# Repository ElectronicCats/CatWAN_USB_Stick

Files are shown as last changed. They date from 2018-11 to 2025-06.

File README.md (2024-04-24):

# CatWAN USB Stick
<p align="center">
    <a href="https://github.com/ElectronicCats/CatWAN_USB_Stick/wiki">
        CatWANShield
    </a>
</p>

<p align=center>
    <a href="https://electroniccats.com/store/catwan-usb-stick">
        
    </a>
    <a href="https://github.com/ElectronicCats/CatWAN_USB_Stick/wiki">
        
    </a>
</p>

<p align=center>
Also available at distributors:
</p>
<p align=center>
<a href="https://labs.ksec.co.uk/product-category/electronic-cat/">

</a>
</p>

Are you interested in learning how LoRa works at the package level? Debugging your own LoRa hardware and trying to detect where something is wrong? Or maybe you're writing a custom application for your Internet of Things (IoT) network with LoraWAN? We have the perfect tool for you!

This CatWAN USB Stick is programmed with a special firmware image that makes it an easy-to-use LoRa sniffer. You can passively capture the data exchanges between two LoRa devices, capturing with our "LoRa Sniffer" the open-source network analysis tool that we have created to use together.

This device can work in networks LoRaWAN compatible with classes A, B, and C, although currently we do not have a firmware for this way of working, the CatWAN firmware is completely open source and you can find it in our repository along with the schematic. If you want to reprogram this device you can do it through Arduino IDE and its USB port or if you do not have to use a J-Link. ATMEL-ICE or a DIY SWD programmer

This device has a SAMD21 ARM Cortex microcontroller at 48Mhz with native USB 2.1, with 256Kb for programming, compatible with Arduino and Circuit Python.

Check our repository for more details and software downloads!

### Main characteristics

- Works with any PC, Raspberry Pi or BeagleBone, even a smartphone or tablet
- Supports packet mode LoRa® (package mode) or LoRaWAN ™ Class A, B and C
- Compatible with The Things Network and other LoRaWAN networks
- Based on the RFM95
- RX LED as reception indicator, programmable by the user
- Easy reprogramming compatible with Arduino and Circuit Python
- Compatible with the [App LoRa Sniffer](https://github.com/ElectronicCats/LoRa_Sniffer)
- Open Source

### Specifications

- Connectivity: USB 2.1
- Power Consumption: 140 ma typical TX, 20 ma idle (with power LED)
- Receiver Sensitivity: down to -146 dBm
- TX Power: adjustable up to +18.5 dBm
- Range: up to 15 km coverage in suburban and up to 5 km coverage in urban areas

### Pin connections

|Arduino | Port | RFM Function|
|---|---|---|
|0 | PORTA4  | DIO0 |
|1 | PORTA23 | DIO1 |
|2 | PORTA27 | DIO2 |
|13 | PORTA14 | LED |
|15 | PORTA15 | DIO5 |
|17 | PORTA22 | MISO |
|18 | PORTA18 | MOSI |
|19 | PORTA19 | SCK |
|20 | PORTA17 | SS |

## How to contribute 
 Contributions are welcome! 

Please read the document  [**Contribution Manual**](https://github.com/ElectronicCats/electroniccats-cla/blob/main/electroniccats-contribution-manual.md)  which will show you how to contribute your changes to the project.

✨ Thanks to all our [contributors](https://github.com/ElectronicCats/CatWAN_USB_Stick/graphs/contributors)! ✨

See  [**_Electronic Cats CLA_**](https://github.com/ElectronicCats/electroniccats-cla/blob/main/electroniccats-cla.md) for more information.

See the [**community code of conduct**](https://github.com/ElectronicCats/electroniccats-cla/blob/main/electroniccats-community-code-of-conduct.md)   for a vision of the community we want to build and what we expect from it.

### Maintainer

Electronic Cats invests time and resources in providing this open-source design design, please support Electronic Cats and open-source hardware by purchasing products from Electronic Cats!

<a href="https://github.com/sponsors/ElectronicCats">
  
</a>

## Open Source certified.
<p align="center">
    <a href="https://www.oshwa.org/cert">
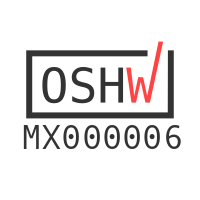
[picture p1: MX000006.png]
CatWANShield
        
        <br>
        <strong>[OSHW] MX000006 | Certified open source hardware |</strong>
    </a>
</p>

Designed by Electronic Cats.

Firmware released under an GNU AGPL v3.0 license. See the LICENSE file for more information.

Hardware released under an CERN Open Hardware Licence v1.2. See the LICENSE_HARDWARE file for more information.

Electronic Cats is a registered trademark, please do not use if you sell these PCBs.

27 May 2019

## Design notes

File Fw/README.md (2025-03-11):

# Firmware examples
This folder contains 3 sub-folders:

- LoRaWAN
- LoRa-PHY
- bootloader_uf2 for only SAMD21 version

The sub-folder bootloader_uf2 has inside all the files that can be use to re-flash your CatWAN USB-Stick in case of hard brick it.

The sub-folders LoRa and LoRaWAN have inside its own examples about a posible implementation of LoRa from LoRa physical layer to some LoRaWAN implementations. 

## LoRaWAN Folder
Here you will find three possible ways to implement a LoRaWAN Stack:

- LoRa_WAN_Sniffer_REG
	Which is an example where you only require the SPI library and all the registers inside the radio are modified just as the LoRaWAN stack says.

- LMIC_library 
	In this folder you'll find two examples about an implementation of the LoRaWAN Stack with the LMIC library with the two types of activations, ABP and OTAA, both examples are a class A node, for this examples you MUST install the [LMIC library](https://github.com/things-nyc/arduino-lmic).
	
- ArduinoLoRaWAN_library 
	In this folder you'll find an example of the LoRaWAN stack implementation with the ArduinoLoRaWAN library which is simple than the LMIC implementation, for this examples you MUST install the [Arduino LoRaWAN library](https://github.com/BeelanMX/arduino-LoRaWAN)
	
## LoRa_PHY 
Here you'
ll find the simplest examples to use the LoRa radio just using the physical layer of LoRa 

- "LoRaReceiverCallback" 
   Will receive any LoRa data from an interrupt
- "LoRaSender" 
	Will send data on the physical layer of LoRa
- "LoRa_PHY_Sniffer"
	Will receive any packet an is under development to configure the radio over serial communication
- "Relay Stick"
	Will communicate with the CatWAN Relay board to control and monitor relays.
- "LoRaReceiver"
    Will receive any LoRa data without an interrupt
- "LoRaSniffer"

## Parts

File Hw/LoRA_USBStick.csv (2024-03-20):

# | Reference | Qty | Value | Footprint | DNP | LCSC# | manf#
1 | AE1 | 1 | Antenna_Shield | agroin:SMA_EDGE |  | C2913580
2 | C1, C3 | 2 | 27pF | Capacitor_SMD:C_0603_1608Metric |  |  | C0603C270J5GAC7411
3 | C2, C9 | 2 | 1uF | Capacitor_SMD:C_0603_1608Metric |  | C711096
4 | C4, C8, C10, C11, C12, C13, C14, C15, C16, C17 | 10 | 0.1uF | Capacitor_SMD:C_0603_1608Metric |  | C282519
5 | C5 | 1 | 0.1uF | Capacitor_SMD:C_0805_2012Metric_Pad1.15x1.40mm_HandSolder |  |  | 885012207072
6 | C6, C7 | 2 | 10uF | Capacitor_SMD:C_0805_2012Metric_Pad1.15x1.40mm_HandSolder |  | C1713
7 | D1 | 1 | Rx | LED_SMD:LED_0805_2012Metric_Pad1.15x1.40mm_HandSolder |  |  | APT2012SGC
8 | D2 | 1 | ON | LED_SMD:LED_0805_2012Metric_Pad1.15x1.40mm_HandSolder |  |  | AP2012EC
9 | J10 | 1 | USB_B | Connectors:C46394 |  | C46394
10 | JP1 | 1 | BOOT | Jumper:SolderJumper-2_P1.3mm_Open_Pad1.0x1.5mm | DNP
11 | R2 | 1 | 1K | Resistor_SMD:R_0603_1608Metric |  | C21190
12 | R3, R4 | 2 | 27 | Resistor_SMD:R_0603_1608Metric |  | C2907136
13 | R5 | 1 | 10K | Resistor_SMD:R_0603_1608Metric |  | C2930027
14 | R9, R11 | 2 | 120R | Resistor_SMD:R_0603_1608Metric |  |  | RMC1/10K1200FTP
15 | SW3 | 1 | RST | Switches:C455281 |  |  | B3U-1000P
16 | U1 | 1 | RP2040 | RP2040:RP2040-QFN-56 |  | C2040
17 | U2 | 1 | RFM95W-868S2 | RF_Module:HOPERF_RFM9XW_SMD |  |  | 109990166
18 | U3 | 1 | AP2112K-3.3 | Package_TO_SOT_SMD:SOT-23-5 |  |  | AP7365-33WG-7
19 | U4 | 1 | W25Q16JV | RP2040:W25Q16JVUUIQ |  |  | W25Q16JVUUIQTR
20 | Y1 | 1 | 12Mhz | Crystal:Crystal_SMD_5032-2Pin_5.0x3.2mm |  |  | ECS-120-18-30-JGN-TR

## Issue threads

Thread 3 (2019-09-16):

Can't program LoRa sniffer firmware to V1.0 board

Miceuz, 2019-09-16:
This is the build log I get:

This is build log I get when programming LoRa sniffer:

/home/miceuz/arduino/arduino-builder -dump-prefs -logger=machine -hardware /home/miceuz/arduino/hardware -hardware /home/miceuz/.arduino15/packages -tools /home/miceuz/arduino/tools-builder -tools /home/miceuz/arduino/hardware/tools/avr -tools /home/miceuz/.arduino15/packages -built-in-libraries /home/miceuz/arduino/libraries -libraries /home/miceuz/Arduino/libraries -fqbn=electroniccats:samd:electroniccats_USB_Stick -vid-pid=0X1209_0XBAB2 -ide-version=10807 -build-path /tmp/arduino_build_279491 -warnings=none -build-cache /tmp/arduino_cache_751360 -prefs=build.warn_data_percentage=75 -prefs=runtime.tools.CMSIS-Atmel.path=/home/miceuz/.arduino15/packages/arduino/tools/CMSIS-Atmel/1.2.0 -prefs=runtime.tools.CMSIS-Atmel-1.2.0.path=/home/miceuz/.arduino15/packages/arduino/tools/CMSIS-Atmel/1.2.0 -prefs=runtime.tools.arm-none-eabi-gcc.path=/home/miceuz/.arduino15/packages/arduino/tools/arm-none-eabi-gcc/4.8.3-2014q1 -prefs=runtime.tools.arm-none-eabi-gcc-4.8.3-2014q1.path=/home/miceuz/.arduino15/packages/arduino/tools/arm-none-eabi-gcc/4.8.3-2014q1 -prefs=runtime.tools.bossac.path=/home/miceuz/.arduino15/packages/arduino/tools/bossac/1.8.0-48-gb176eee -prefs=runtime.tools.bossac-1.8.0-48-gb176eee.path=/home/miceuz/.arduino15/packages/arduino/tools/bossac/1.8.0-48-gb176eee -prefs=runtime.tools.openocd.path=/home/miceuz/.arduino15/packages/arduino/tools/openocd/0.9.0-arduino -prefs=runtime.tools.openocd-0.9.0-arduino.path=/home/miceuz/.arduino15/packages/arduino/tools/openocd/0.9.0-arduino -prefs=runtime.tools.CMSIS.path=/home/miceuz/.arduino15/packages/arduino/tools/CMSIS/4.5.0 -prefs=runtime.tools.CMSIS-4.5.0.path=/home/miceuz/.arduino15/packages/arduino/tools/CMSIS/4.5.0 -verbose /home/miceuz/Arduino/LoRaSniffer/LoRaSniffer.ino
/home/miceuz/arduino/arduino-builder -compile -logger=machine -hardware /home/miceuz/arduino/hardware -hardware /home/miceuz/.arduino15/packages -tools /home/miceuz/arduino/tools-builder -tools /home/miceuz/arduino/hardware/tools/avr -tools /home/miceuz/.arduino15/packages -built-in-libraries /home/miceuz/arduino/libraries -libraries /home/miceuz/Arduino/libraries -fqbn=electroniccats:samd:electroniccats_USB_Stick -vid-pid=0X1209_0XBAB2 -ide-version=10807 -build-path /tmp/arduino_build_279491 -warnings=none -build-cache /tmp/arduino_cache_751360 -prefs=build.warn_data_percentage=75 -prefs=runtime.tools.CMSIS-Atmel.path=/home/miceuz/.arduino15/packages/arduino/tools/CMSIS-Atmel/1.2.0 -prefs=runtime.tools.CMSIS-Atmel-1.2.0.path=/home/miceuz/.arduino15/packages/arduino/tools/CMSIS-Atmel/1.2.0 -prefs=runtime.tools.arm-none-eabi-gcc.path=/home/miceuz/.arduino15/packages/arduino/tools/arm-none-eabi-gcc/4.8.3-2014q1 -prefs=runtime.tools.arm-none-eabi-gcc-4.8.3-2014q1.path=/home/miceuz/.arduino15/packages/arduino/tools/arm-none-eabi-gcc/4.8.3-2014q1 -prefs=runtime.tools.bossac.path=/home/miceuz/.arduino15/packages/arduino/tools/bossac/1.8.0-48-gb176eee -prefs=runtime.tools.bossac-1.8.0-48-gb176eee.path=/home/miceuz/.arduino15/packages/arduino/tools/bossac/1.8.0-48-gb176eee -prefs=runtime.tools.openocd.path=/home/miceuz/.arduino15/packages/arduino/tools/openocd/0.9.0-arduino -prefs=runtime.tools.openocd-0.9.0-arduino.path=/home/miceuz/.arduino15/packages/arduino/tools/openocd/0.9.0-arduino -prefs=runtime.tools.CMSIS.path=/home/miceuz/.arduino15/packages/arduino/tools/CMSIS/4.5.0 -prefs=runtime.tools.CMSIS-4.5.0.path=/home/miceuz/.arduino15/packages/arduino/tools/CMSIS/4.5.0 -verbose /home/miceuz/Arduino/LoRaSniffer/LoRaSniffer.ino
Using board 'electroniccats_USB_Stick' from platform in folder: /home/miceuz/.arduino15/packages/electroniccats/hardware/samd/1.1.1
Using core 'arduino' from platform in folder: /home/miceuz/.arduino15/packages/electroniccats/hardware/samd/1.1.1
Build options changed, rebuilding all
Detecting libraries used...
/home/miceuz/.arduino15/packages/arduino/tools/arm-none-eabi-gcc/4.8.3-2014q1/bin/arm-none-eabi-g++ -mcpu=cortex-m0plus -mthumb -c -g -Os -w -std=gnu++11 -ffunction-sections -fdata-sections -fno-threadsafe-statics -nostdlib --param max-inline-insns-single=500 -fno-rtti -fno-exceptions -w -x c++ -E -CC -DF_CPU=48000000L -DARDUINO=10807 -DARDUINO_catwan_usb_stick -DARDUINO_ARCH_SAMD -DCRYSTALLESS -DARDUINO_SAMD_ZERO -D__SAMD21E18A__ -DARM_MATH_CM0PLUS -DUSB_VID=0x1209 -DUSB_PID=0xBAB2 -DUSBCON "-DUSB_MANUFACTURER=\"Electronic Cats\"" "-DUSB_PRODUCT=\"CatWAN USB_Stick\"" -I/home/miceuz/.arduino15/packages/arduino/tools/CMSIS/4.5.0/CMSIS/Include/ -I/home/miceuz/.arduino15/packages/arduino/tools/CMSIS-Atmel/1.2.0/CMSIS/Device/ATMEL/ -I/home/miceuz/.arduino15/packages/electroniccats/hardware/samd/1.1.1/cores/arduino -I/home/miceuz/.arduino15/packages/electroniccats/hardware/samd/1.1.1/variants/catwan_usb_stick /tmp/arduino_build_279491/sketch/LoRaSniffer.ino.cpp -o /dev/null
/home/miceuz/.arduino15/packages/arduino/tools/arm-none-eabi-gcc/4.8.3-2014q1/bin/arm-none-eabi-g++ -mcpu=cortex-m0plus -mthumb -c -g -Os -w -std=gnu++11 -ffunction-sections -fdata-sections -fno-threadsafe-statics -nostdlib --param max-inline-insns-single=500 -fno-rtti -fno-exceptions -w -x c++ -E -CC -DF_CPU=48000000L -DARDUINO=10807 -DARDUINO_catwan_usb_stick -DARDUINO_ARCH_SAMD -DCRYSTALLESS -DARDUINO_SAMD_ZERO -D__SAMD21E18A__ -DARM_MATH_CM0PLUS -DUSB_VID=0x1209 -DUSB_PID=0xBAB2 -DUSBCON "-DUSB_MANUFACTURER=\"Electronic Cats\"" "-DUSB_PRODUCT=\"CatWAN USB_Stick\"" -I/home/miceuz/.arduino15/packages/arduino/tools/CMSIS/4.5.0/CMSIS/Include/ -I/home/miceuz/.arduino15/packages/arduino/tools/CMSIS-Atmel/1.2.0/CMSIS/Device/ATMEL/ -I/home/miceuz/.arduino15/packages/electroniccats/hardware/samd/1.1.1/cores/arduino -I/home/miceuz/.arduino15/packages/electroniccats/hardware/samd/1.1.1/variants/catwan_usb_stick -I/home/miceuz/Arduino/libraries/ArduinoSerialCommand /tmp/arduino_build_279491/sketch/LoRaSniffer.ino.cpp -o /dev/null
/home/miceuz/.arduino15/packages/arduino/tools/arm-none-eabi-gcc/4.8.3-2014q1/bin/arm-none-eabi-g++ -mcpu=cortex-m0plus -mthumb -c -g -Os -w -std=gnu++11 -ffunction-sections -fdata-sections -fno-threadsafe-statics -nostdlib --param max-inline-insns-single=500 -fno-rtti -fno-exceptions -w -x c++ -E -CC -DF_CPU=48000000L -DARDUINO=10807 -DARDUINO_catwan_usb_stick -DARDUINO_ARCH_SAMD -DCRYSTALLESS -DARDUINO_SAMD_ZERO -D__SAMD21E18A__ -DARM_MATH_CM0PLUS -DUSB_VID=0x1209 -DUSB_PID=0xBAB2 -DUSBCON "-DUSB_MANUFACTURER=\"Electronic Cats\"" "-DUSB_PRODUCT=\"CatWAN USB_Stick\"" -I/home/miceuz/.arduino15/packages/arduino/tools/CMSIS/4.5.0/CMSIS/Include/ -I/home/miceuz/.arduino15/packages/arduino/tools/CMSIS-Atmel/1.2.0/CMSIS/Device/ATMEL/ -I/home/miceuz/.arduino15/packages/electroniccats/hardware/samd/1.1.1/cores/arduino -I/home/miceuz/.arduino15/packages/electroniccats/hardware/samd/1.1.1/variants/catwan_usb_stick -I/home/miceuz/Arduino/libraries/ArduinoSerialCommand -I/home/miceuz/.arduino15/packages/electroniccats/hardware/samd/1.1.1/libraries/SPI /tmp/arduino_build_279491/sketch/LoRaSniffer.ino.cpp -o /dev/null
/home/miceuz/.arduino15/packages/arduino/tools/arm-none-eabi-gcc/4.8.3-2014q1/bin/arm-none-eabi-g++ -mcpu=cortex-m0plus -mthumb -c -g -Os -w -std=gnu++11 -ffunction-sections -fdata-sections -fno-threadsafe-statics -nostdlib --param max-inline-insns-single=500 -fno-rtti -fno-exceptions -w -x c++ -E -CC -DF_CPU=48000000L -DARDUINO=10807 -DARDUINO_catwan_usb_stick -DARDUINO_ARCH_SAMD -DCRYSTALLESS -DARDUINO_SAMD_ZERO -D__SAMD21E18A__ -DARM_MATH_CM0PLUS -DUSB_VID=0x1209 -DUSB_PID=0xBAB2 -DUSBCON "-DUSB_MANUFACTURER=\"Electronic Cats\"" "-DUSB_PRODUCT=\"CatWAN USB_Stick\"" -I/home/miceuz/.arduino15/packages/arduino/tools/CMSIS/4.5.0/CMSIS/Include/ -I/home/miceuz/.arduino15/packages/arduino/tools/CMSIS-Atmel/1.2.0/CMSIS/Device/ATMEL/ -I/home/miceuz/.arduino15/packages/electroniccats/hardware/samd/1.1.1/cores/arduino -I/home/miceuz/.arduino15/packages/electroniccats/hardware/samd/1.1.1/variants/catwan_usb_stick -I/home/miceuz/Arduino/libraries/ArduinoSerialCommand -I/home/miceuz/.arduino15/packages/electroniccats/hardware/samd/1.1.1/libraries/SPI -I/home/miceuz/Arduino/libraries/LoRa/src /tmp/arduino_build_279491/sketch/LoRaSniffer.ino.cpp -o /dev/null
/home/miceuz/.arduino15/packages/arduino/tools/arm-none-eabi-gcc/4.8.3-2014q1/bin/arm-none-eabi-g++ -mcpu=cortex-m0plus -mthumb -c -g -Os -w -std=gnu++11 -ffunction-sections -fdata-sections -fno-threadsafe-statics -nostdlib --param max-inline-insns-single=500 -fno-rtti -fno-exceptions -w -x c++ -E -CC -DF_CPU=48000000L -DARDUINO=10807 -DARDUINO_catwan_usb_stick -DARDUINO_ARCH_SAMD -DCRYSTALLESS -DARDUINO_SAMD_ZERO -D__SAMD21E18A__ -DARM_MATH_CM0PLUS -DUSB_VID=0x1209 -DUSB_PID=0xBAB2 -DUSBCON "-DUSB_MANUFACTURER=\"Electronic Cats\"" "-DUSB_PRODUCT=\"CatWAN USB_Stick\"" -I/home/miceuz/.arduino15/packages/arduino/tools/CMSIS/4.5.0/CMSIS/Include/ -I/home/miceuz/.arduino15/packages/arduino/tools/CMSIS-Atmel/1.2.0/CMSIS/Device/ATMEL/ -I/home/miceuz/.arduino15/packages/electroniccats/hardware/samd/1.1.1/cores/arduino -I/home/miceuz/.arduino15/packages/electroniccats/hardware/samd/1.1.1/variants/catwan_usb_stick -I/home/miceuz/Arduino/libraries/ArduinoSerialCommand -I/home/miceuz/.arduino15/packages/electroniccats/hardware/samd/1.1.1/libraries/SPI -I/home/miceuz/Arduino/libraries/LoRa/src /home/miceuz/Arduino/libraries/ArduinoSerialCommand/SerialCommand.cpp -o /dev/null
/home/miceuz/.arduino15/packages/arduino/tools/arm-none-eabi-gcc/4.8.3-2014q1/bin/arm-none-eabi-g++ -mcpu=cortex-m0plus -mthumb -c -g -Os -w -std=gnu++11 -ffunction-sections -fdata-sections -fno-threadsafe-statics -nostdlib --param max-inline-insns-single=500 -fno-rtti -fno-exceptions -w -x c++ -E -CC -DF_CPU=48000000L -DARDUINO=10807 -DARDUINO_catwan_usb_stick -DARDUINO_ARCH_SAMD -DCRYSTALLESS -DARDUINO_SAMD_ZERO -D__SAMD21E18A__ -DARM_MATH_CM0PLUS -DUSB_VID=0x1209 -DUSB_PID=0xBAB2 -DUSBCON "-DUSB_MANUFACTURER=\"Electronic Cats\"" "-DUSB_PRODUCT=\"CatWAN USB_Stick\"" -I/home/miceuz/.arduino15/packages/arduino/tools/CMSIS/4.5.0/CMSIS/Include/ -I/home/miceuz/.arduino15/packages/arduino/tools/CMSIS-Atmel/1.2.0/CMSIS/Device/ATMEL/ -I/home/miceuz/.arduino15/packages/electroniccats/hardware/samd/1.1.1/cores/arduino -I/home/miceuz/.arduino15/packages/electroniccats/hardware/samd/1.1.1/variants/catwan_usb_stick -I/home/miceuz/Arduino/libraries/ArduinoSerialCommand -I/home/miceuz/.arduino15/packages/electroniccats/hardware/samd/1.1.1/libraries/SPI -I/home/miceuz/Arduino/libraries/LoRa/src /home/miceuz/.arduino15/packages/electroniccats/hardware/samd/1.1.1/libraries/SPI/SPI.cpp -o /dev/null
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
Miceuz, 2019-09-16:
Upon closer inspection I have noticed that two pads of RFM95 module were hanging above board, not soldered. Works after fixing this.

wero1414, 2019-09-17:
Great! I'm really ashamed that you needed to solder those RFM pins i really apologize, all the hardware that we provide is tested before shipping but i guess we miss one quality procedure.

If you want to buy any other thing from us we can give a discount to you cause this situation.

Closed 2019-09-17.

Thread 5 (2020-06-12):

Lack of build instructions

BatchDrake, 2020-06-12:
Hi all,

I'm trying to use the LoRa PHY Sniffer example, but I'm having trouble making it work. First of all, after installing the corresponding board description as you suggest in your README, I faced the following build issue:

```
LoRaSniffer:20:27: fatal error: SerialCommand.h: No such file or directory
 #include <SerialCommand.h>
```

My guess was that it depended on `SerialCommand`, but this library does not show up in the library manager. I looked it up on GitHub and, after finding multiple mutually-incompatible implementations of the same library, I came across this one (https://github.com/kroimon/Arduino-SerialCommand) which seemed to build. The problem now is that LoRaSniffer does not get past these lines:

```c++
void setup(){
  pinMode(LED_BUILTIN,OUTPUT);      // Configure the onboard LED for output
  digitalWrite(LED_BUILTIN,LOW);    // default to LED off
  pinMode(RFM_DIO5,INPUT);
  Serial.begin(115200);
  while (!Serial);
```

which don't seem to be related to `SerialCommand` at all. I know the bootloader works because if I set the `LED_BUILTIN` to `HIGH` right before initializing the serial, the green LED lights it up. However, if I set it right after the `while(!Serial)`, the LED remains switched off.

I think I may be missing a primary source of documentation here. The only thing I need is to read the contents of the LoRa PHY frames from Putty, that would be pretty much it. Is there a guide somewhere with detailed steps on how to build & use this sniffer?

Thanks!

sabas1080, 2020-06-12:
Hi @BatchDrake

`  while (!Serial);`

wait for serial port to open via Arduino IDE or Putty, after that you would see

```
  Serial.println("Welcome to the LoRa Sniffer CLI " + String(fwVersion,1) + "v\n");
  Serial.println("With this sketch you can scan the LoRa spectrum");
  Serial.println("Changing the Frequency, Spreading Factor, BandWidth or the IQ signals of the radio.");
  Serial.println("Type help to get the available commands.");
  Serial.println("Electronic Cats ® 2020");
```
if you don´t open serial port, the program will not advance

BatchDrake, 2020-06-12:
Waited for minutes with no results. Pressing Enter or typing `help` didn't
work either. Port speed was 115200.

El vie., 12 jun. 2020 19:34, Sabas <notifications@github.com> escribió:

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

sabas1080, 2020-06-12:
You have to active in serial monitor New Line and carriage Return and send command "help please"

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

BatchDrake, 2020-06-15:
Okay, it works now. Thanks!

Closed 2020-06-15.

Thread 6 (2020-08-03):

no 3.3V output and bootloader issue(not sure)

vileer, 2020-08-03:
I am trying to make my own board with the USB type-c connector but it didn't work, after review the hw design, I found the AP2112k-3.3 EN pin does not connect to the hight voltage which means no 3.3v output. After I connect the EN pin to VBUS, led lights up and able to program the bootloader. The official catwan stick I bought from tindie didn't have this issue.

But here comes the new problem, after flash the bootloader and plug it into the pc, nothing happens no USB-Serial port show in the Arduino IDE.

sabas1080, 2020-08-03:
Hi @vileer

it seems this change I don't update, we have repaired the LDO.

About the bootloader, are you pressing the reset button twice quickly and going into boot mode?

vileer, 2020-08-04:
@sabas1080 Yes, I did double click the reset button quickly, but nothing happens.

vileer, 2020-08-04:
Here is my fuses setting, may that help you to diagnos the problem：
SERIAL_NUMBER_3 = 0x41F61D1A
SERIAL_NUMBER_0 = 0x51514B32
SERIAL_NUMBER_1 = 0x53202020
SERIAL_NUMBER_2 = 0xFF07392C
ADC_LINEARITY_0 = 0x08
ADC_LINEARITY_1 = 0x04
ADC_BIASCAL = 0x03
OSC32K_CAL = 0x32
USB_TRANSN = 0x09
USB_TRANSP = 0x19
USB_TRIM = 0x06
DFLL48M_COARSE_CAL = 0x1E
DFLL48M_FINE_CAL = 0x200
ROOM_TEMP_VAL_INT = 0x1E
ROOM_TEMP_VAL_DEC = 0x01
HOT_TEMP_VAL_INT = 0x55
HOT_TEMP_VAL_DEC = 0x00
ROOM_INT1V_VAL = 0xF7
HOT_INT1V_VAL = 0xF4
ROOM_ADC_VAL = 0xAFA
HOT_ADC_VAL = 0xD1E
NVMCTRL_BOOTPROT = SIZE_0BYTES
NVMCTRL_EEPROM_SIZE = SIZE_0BYTES
BOD33USERLEVEL = 0x07
BOD33_EN = ENABLED
BOD33_ACTION = RESET
WDT_ENABLE = DISABLED
WDT_ALWAYSON = DISABLED
WDT_PER = CYC16384
WDT_WINDOW_0 = [X]
WDT_WINDOW_1 = 0x05
WDT_EWOFFSET = CYC16384
WDT_WEN = DISABLED
BOD33_HYST = DISABLED
NVMCTRL_REGION_LOCKS = 0xFFFF

AUX3_WORD_3 = 0x41F61D1A (valid)
AUX3_WORD_16 = 0x51514B32 (valid)
AUX3_WORD_17 = 0x53202020 (valid)
AUX3_WORD_18 = 0xFF07392C (valid)
OTP4_WORD_0 = 0x40004007 (valid)
OTP4_WORD_1 = 0x7B652C9C (valid)
OTP4_WORD_2 = 0xFFFFFE00 (valid)
TEMP_LOG_WORD_0 = 0xF705511E (valid)
TEMP_LOG_WORD_1 = 0xD1EAFAF4 (valid)
USER_WORD_0 = 0xD8E0C7FF (valid)
USER_WORD_1 = 0xFFFFFC5D (valid)

sabas1080, 2020-08-04:
which bootloader are you using? Can you show me the schematic of you board?

vileer, 2020-08-05:
I've tried the [bootloader binary file](https://github.com/ElectronicCats/CatWAN_USB_Stick/blob/master/Fw/bootloader_uf2/bootloader-catwan-usb-stick-v3.4.0-70-g3a14b0b-dirty.bin) and the [bootloader elf format file](https://github.com/ElectronicCats/CatWAN_USB_Stick/blob/master/Fw/bootloader_uf2/bootloader-catwan-usb-stick-v3.4.0-70-g3a14b0b-dirty.elf). I follow this [tutorial](https://learn.adafruit.com/proper-step-debugging-atsamd21-arduino-zero-m0/restoring-bootloader) to flash the bootloader by using the J-Link EDU Mini.
the schematic is based on the master repo and changes the USB type-a connector to the usb-c one.
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

sabas1080, 2020-08-05:
looks good, It is difficult to know what is happening, but I would verify the following:
- that the device is listed USB, the led should blink slowly once listed
- connection on USB terminals
- the reset button bounces and the device never enters boot mode

wero1414, 2020-08-13:
Hi @vileer any new on this problem?

vileer, 2020-10-15:
@wero1414 @sabas1080 the bootloader “issues” solved. Turn out that using the wrong chip, the schematic claim to use the ATSAMD21E15B-AUT as the controller but after check the board I brought from tindie the chip actually is ATSAMD21E18A-U, after changing the chip and reflash the bootloader, the bootloader is recognized by the pc.

sabas1080, 2020-10-15:
@vileer oh sorry, I going to change chip

vileer, 2020-10-16:
@sabas1080 it is ok, this the charm of an open-source project we can work together to make it successful.

Closed 2020-08-26.

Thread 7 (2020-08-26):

Protective shell 3D model file

BG7YWL, 2020-08-26:
Is the 3D file of this protective case public?
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

wero1414, 2020-08-26:
Hello we dont have the 3D file for the case, cause the manufacturer hasnt publish the 3D file on the link below you will find the description of the case and a 2D PDF with all the measures.

https://www.newageenclosures.com/enclosures/usb-enclosures/mini-remote.php

Closed 2020-08-26.

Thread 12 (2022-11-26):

Error compiling LoRaSniffer code

c4nh0t0, 2022-11-26:
Hey folks, I'm having an issue while trying to compile the LoRaSniffer.ino code and I'm having those issues as shown in print screen

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

I have all libraries installed (LoRa, ElectronicaCats, SerialCommand). Do you folks have any clue about this?
Thanks!

REGIOIGER, 2022-11-26:
Hi c4nh0t0, are you using the SerialCommand kroimon library?
https://github.com/kroimon/Arduino-SerialCommand

c4nh0t0, 2022-11-27:
I don't think so. I'm using SerialCommand library by Hugo Arganda and Daniel Castellon, installed directly by Arduino IDE Library Manager.
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

REGIOIGER, 2022-11-28:
Please, use the https://github.com/kroimon/Arduino-SerialCommand library, unistall SerialCommand library by Hugo Arganda and Daniel Castellon first, tell me if works

c4nh0t0, 2022-11-29:
It worked! Awesome mate.
Many thanks.

Closed 2022-11-29.

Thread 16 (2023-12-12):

error

S5647787, 2023-12-12:
i get this error when i run  my code.
/opt/arduino-1.8.19/arduino-builder -dump-prefs -logger=machine -hardware /opt/arduino-1.8.19/hardware -hardware /home/raspberry/.arduino15/packages -tools /opt/arduino-1.8.19/tools-builder -tools /opt/arduino-1.8.19/hardware/tools/avr -tools /home/raspberry/.arduino15/packages -built-in-libraries /opt/arduino-1.8.19/libraries -libraries /home/raspberry/.arduino15/libraries -fqbn=electroniccats:samd:electroniccats_USB_Stick -vid-pid=1209_BAB2 -ide-version=10819 -build-path /tmp/arduino_build_791481 -warnings=default -build-cache /tmp/arduino_cache_624823 -prefs=build.warn_data_percentage=75 -prefs=runtime.tools.bossac.path=/home/raspberry/.arduino15/packages/arduino/tools/bossac/1.8.0-48-gb176eee -prefs=runtime.tools.bossac-1.8.0-48-gb176eee.path=/home/raspberry/.arduino15/packages/arduino/tools/bossac/1.8.0-48-gb176eee -prefs=runtime.tools.arm-none-eabi-gcc.path=/home/raspberry/.arduino15/packages/arduino/tools/arm-none-eabi-gcc/4.8.3-2014q1 -prefs=runtime.tools.arm-none-eabi-gcc-4.8.3-2014q1.path=/home/raspberry/.arduino15/packages/arduino/tools/arm-none-eabi-gcc/4.8.3-2014q1 -prefs=runtime.tools.CMSIS.path=/home/raspberry/.arduino15/packages/arduino/tools/CMSIS/4.5.0 -prefs=runtime.tools.CMSIS-4.5.0.path=/home/raspberry/.arduino15/packages/arduino/tools/CMSIS/4.5.0 -prefs=runtime.tools.CMSIS-Atmel.path=/home/raspberry/.arduino15/packages/arduino/tools/CMSIS-Atmel/1.2.0 -prefs=runtime.tools.CMSIS-Atmel-1.2.0.path=/home/raspberry/.arduino15/packages/arduino/tools/CMSIS-Atmel/1.2.0 -prefs=runtime.tools.openocd.path=/home/raspberry/.arduino15/packages/arduino/tools/openocd/0.9.0-arduino -prefs=runtime.tools.openocd-0.9.0-arduino.path=/home/raspberry/.arduino15/packages/arduino/tools/openocd/0.9.0-arduino -verbose /home/raspberry/Desktop/sketch_dec06a/final/final.ino
/opt/arduino-1.8.19/arduino-builder -compile -logger=machine -hardware /opt/arduino-1.8.19/hardware -hardware /home/raspberry/.arduino15/packages -tools /opt/arduino-1.8.19/tools-builder -tools /opt/arduino-1.8.19/hardware/tools/avr -tools /home/raspberry/.arduino15/packages -built-in-libraries /opt/arduino-1.8.19/libraries -libraries /home/raspberry/.arduino15/libraries -fqbn=electroniccats:samd:electroniccats_USB_Stick -vid-pid=1209_BAB2 -ide-version=10819 -build-path /tmp/arduino_build_791481 -warnings=default -build-cache /tmp/arduino_cache_624823 -prefs=build.warn_data_percentage=75 -prefs=runtime.tools.bossac.path=/home/raspberry/.arduino15/packages/arduino/tools/bossac/1.8.0-48-gb176eee -prefs=runtime.tools.bossac-1.8.0-48-gb176eee.path=/home/raspberry/.arduino15/packages/arduino/tools/bossac/1.8.0-48-gb176eee -prefs=runtime.tools.arm-none-eabi-gcc.path=/home/raspberry/.arduino15/packages/arduino/tools/arm-none-eabi-gcc/4.8.3-2014q1 -prefs=runtime.tools.arm-none-eabi-gcc-4.8.3-2014q1.path=/home/raspberry/.arduino15/packages/arduino/tools/arm-none-eabi-gcc/4.8.3-2014q1 -prefs=runtime.tools.CMSIS.path=/home/raspberry/.arduino15/packages/arduino/tools/CMSIS/4.5.0 -prefs=runtime.tools.CMSIS-4.5.0.path=/home/raspberry/.arduino15/packages/arduino/tools/CMSIS/4.5.0 -prefs=runtime.tools.CMSIS-Atmel.path=/home/raspberry/.arduino15/packages/arduino/tools/CMSIS-Atmel/1.2.0 -prefs=runtime.tools.CMSIS-Atmel-1.2.0.path=/home/raspberry/.arduino15/packages/arduino/tools/CMSIS-Atmel/1.2.0 -prefs=runtime.tools.openocd.path=/home/raspberry/.arduino15/packages/arduino/tools/openocd/0.9.0-arduino -prefs=runtime.tools.openocd-0.9.0-arduino.path=/home/raspberry/.arduino15/packages/arduino/tools/openocd/0.9.0-arduino -verbose /home/raspberry/Desktop/sketch_dec06a/final/final.ino
Using board 'electroniccats_USB_Stick' from platform in folder: /home/raspberry/.arduino15/packages/electroniccats/hardware/samd/1.2.2
Using core 'arduino' from platform in folder: /home/raspberry/.arduino15/packages/electroniccats/hardware/samd/1.2.2
Detecting libraries used...
/home/raspberry/.arduino15/packages/arduino/tools/arm-none-eabi-gcc/4.8.3-2014q1/bin/arm-none-eabi-g++ -mcpu=cortex-m0plus -mthumb -c -g -Os -w -std=gnu++11 -ffunction-sections -fdata-sections -fno-threadsafe-statics -nostdlib --param max-inline-insns-single=500 -fno-rtti -fno-exceptions -w -x c++ -E -CC -DF_CPU=48000000L -DARDUINO=10819 -DARDUINO_catwan_usb_stick -DARDUINO_ARCH_SAMD -DCRYSTALLESS -DARDUINO_SAMD_ZERO -D__SAMD21E18A__ -DARM_MATH_CM0PLUS -DUSB_VID=0x1209 -DUSB_PID=0xBAB2 -DUSBCON "-DUSB_MANUFACTURER=\"Electronic Cats\"" "-DUSB_PRODUCT=\"CatWAN USB_Stick\"" -I/home/raspberry/.arduino15/packages/arduino/tools/CMSIS/4.5.0/CMSIS/Include/ -I/home/raspberry/.arduino15/packages/arduino/tools/CMSIS-Atmel/1.2.0/CMSIS/Device/ATMEL/ -I/home/raspberry/.arduino15/packages/electroniccats/hardware/samd/1.2.2/cores/arduino -I/home/raspberry/.arduino15/packages/electroniccats/hardware/samd/1.2.2/variants/catwan_usb_stick /tmp/arduino_build_791481/sketch/final.ino.cpp -o /dev/null
Alternatives for SerialCommand.h: [SerialCommand@2.0.1 Arduino-SerialCommand-master ArduinoSerialCommand-master SerialCommand_Advanced@1.0.0]
ResolveLibrary(SerialCommand.h)
  -> candidates: [SerialCommand@2.0.1 Arduino-SerialCommand-master ArduinoSerialCommand-master SerialCommand_Advanced@1.0.0]
/home/raspberry/.arduino15/packages/arduino/tools/arm-none-eabi-gcc/4.8.3-2014q1/bin/arm-none-eabi-g++ -mcpu=cortex-m0plus -mthumb -c -g -Os -w -std=gnu++11 -ffunction-sections -fdata-sections -fno-threadsafe-statics -nostdlib --param max-inline-insns-single=500 -fno-rtti -fno-exceptions -w -x c++ -E -CC -DF_CPU=48000000L -DARDUINO=10819 -DARDUINO_catwan_usb_stick -DARDUINO_ARCH_SAMD -DCRYSTALLESS -DARDUINO_SAMD_ZERO -D__SAMD21E18A__ -DARM_MATH_CM0PLUS -DUSB_VID=0x1209 -DUSB_PID=0xBAB2 -DUSBCON "-DUSB_MANUFACTURER=\"Electronic Cats\"" "-DUSB_PRODUCT=\"CatWAN USB_Stick\"" -I/home/raspberry/.arduino15/packages/arduino/tools/CMSIS/4.5.0/CMSIS/Include/ -I/home/raspberry/.arduino15/packages/arduino/tools/CMSIS-Atmel/1.2.0/CMSIS/Device/ATMEL/ -I/home/raspberry/.arduino15/packages/electroniccats/hardware/samd/1.2.2/cores/arduino -I/home/raspberry/.arduino15/packages/electroniccats/hardware/samd/1.2.2/variants/catwan_usb_stick -I/home/raspberry/.arduino15/libraries/SerialCommand/src /tmp/arduino_build_791481/sketch/final.ino.cpp -o /dev/null
Alternatives for SPI.h: [SPI@1.0]
ResolveLibrary(SPI.h)
  -> candidates: [SPI@1.0]
/home/raspberry/.arduino15/packages/arduino/tools/arm-none-eabi-gcc/4.8.3-2014q1/bin/arm-none-eabi-g++ -mcpu=cortex-m0plus -mthumb -c -g -Os -w -std=gnu++11 -ffunction-sections -fdata-sections -fno-threadsafe-statics -nostdlib --param max-inline-insns-single=500 -fno-rtti -fno-exceptions -w -x c++ -E -CC -DF_CPU=48000000L -DARDUINO=10819 -DARDUINO_catwan_usb_stick -DARDUINO_ARCH_SAMD -DCRYSTALLESS -DARDUINO_SAMD_ZERO -D__SAMD21E18A__ -DARM_MATH_CM0PLUS -DUSB_VID=0x1209 -DUSB_PID=0xBAB2 -DUSBCON "-DUSB_MANUFACTURER=\"Electronic Cats\"" "-DUSB_PRODUCT=\"CatWAN USB_Stick\"" -I/home/raspberry/.arduino15/packages/arduino/tools/CMSIS/4.5.0/CMSIS/Include/ -I/home/raspberry/.arduino15/packages/arduino/tools/CMSIS-Atmel/1.2.0/CMSIS/Device/ATMEL/ -I/home/raspberry/.arduino15/packages/electroniccats/hardware/samd/1.2.2/cores/arduino -I/home/raspberry/.arduino15/packages/electroniccats/hardware/samd/1.2.2/variants/catwan_usb_stick -I/home/raspberry/.arduino15/libraries/SerialCommand/src -I/home/raspberry/.arduino15/packages/electroniccats/hardware/samd/1.2.2/libraries/SPI /tmp/arduino_build_791481/sketch/final.ino.cpp -o /dev/null
Alternatives for LoRa.h: [LoRa@0.8.0 arduino-LoRa-master@0.8.0]
ResolveLibrary(LoRa.h)
  -> candidates: [LoRa@0.8.0 arduino-LoRa-master@0.8.0]
/home/raspberry/.arduino15/packages/arduino/tools/arm-none-eabi-gcc/4.8.3-2014q1/bin/arm-none-eabi-g++ -mcpu=cortex-m0plus -mthumb -c -g -Os -w -std=gnu++11 -ffunction-sections -fdata-sections -fno-threadsafe-statics -nostdlib --param max-inline-insns-single=500 -fno-rtti -fno-exceptions -w -x c++ -E -CC -DF_CPU=48000000L -DARDUINO=10819 -DARDUINO_catwan_usb_stick -DARDUINO_ARCH_SAMD -DCRYSTALLESS -DARDUINO_SAMD_ZERO -D__SAMD21E18A__ -DARM_MATH_CM0PLUS -DUSB_VID=0x1209 -DUSB_PID=0xBAB2 -DUSBCON "-DUSB_MANUFACTURER=\"Electronic Cats\"" "-DUSB_PRODUCT=\"CatWAN USB_Stick\"" -I/home/raspberry/.arduino15/packages/arduino/tools/CMSIS/4.5.0/CMSIS/Include/ -I/home/raspberry/.arduino15/packages/arduino/tools/CMSIS-Atmel/1.2.0/CMSIS/Device/ATMEL/ -I/home/raspberry/.arduino15/packages/electroniccats/hardware/samd/1.2.2/cores/arduino -I/home/raspberry/.arduino15/packages/electroniccats/hardware/samd/1.2.2/variants/catwan_usb_stick -I/home/raspberry/.arduino15/libraries/SerialCommand/src -I/home/raspberry/.arduino15/packages/electroniccats/hardware/samd/1.2.2/libraries/SPI -I/home/raspberry/.arduino15/libraries/LoRa/src /tmp/arduino_build_791481/sketch/final.ino.cpp -o /dev/null
Using cached library dependencies for file: /home/raspberry/.arduino15/libraries/SerialCommand/src/SerialCommand.cpp
Using cached library dependencies for file: /home/raspberry/.arduino15/packages/electroniccats/hardware/samd/1.2.2/libraries/SPI/SPI.cpp
Using cached library dependencies for file: /home/raspberry/.arduino15/libraries/LoRa/src/LoRa.cpp
Generating function prototypes...
/home/raspberry/.arduino15/packages/arduino/tools/arm-none-eabi-gcc/4.8.3-2014q1/bin/arm-none-eabi-g++ -mcpu=cortex-m0plus -mthumb -c -g -Os -w -std=gnu++11 -ffunction-sections -fdata-sections -fno-threadsafe-statics -nostdlib --param max-inline-insns-single=500 -fno-rtti -fno-exceptions -w -x c++ -E -CC -DF_CPU=48000000L -DARDUINO=10819 -DARDUINO_catwan_usb_stick -DARDUINO_ARCH_SAMD -DCRYSTALLESS -DARDUINO_SAMD_ZERO -D__SAMD21E18A__ -DARM_MATH_CM0PLUS -DUSB_VID=0x1209 -DUSB_PID=0xBAB2 -DUSBCON "-DUSB_MANUFACTURER=\"Electronic Cats\"" "-DUSB_PRODUCT=\"CatWAN USB_Stick\"" -I/home/raspberry/.arduino15/packages/arduino/tools/CMSIS/4.5.0/CMSIS/Include/ -I/home/raspberry/.arduino15/packages/arduino/tools/CMSIS-Atmel/1.2.0/CMSIS/Device/ATMEL/ -I/home/raspberry/.arduino15/packages/electroniccats/hardware/samd/1.2.2/cores/arduino -I/home/raspberry/.arduino15/packages/electroniccats/hardware/samd/1.2.2/variants/catwan_usb_stick -I/home/raspberry/.arduino15/libraries/SerialCommand/src -I/home/raspberry/.arduino15/packages/electroniccats/hardware/samd/1.2.2/libraries/SPI -I/home/raspberry/.arduino15/libraries/LoRa/src /tmp/arduino_build_791481/sketch/final.ino.cpp -o /tmp/arduino_build_791481/preproc/ctags_target_for_gcc_minus_e.cpp
/opt/arduino-1.8.19/tools-builder/ctags/5.8-arduino11/ctags -u --language-force=c++ -f - --c++-kinds=svpf --fields=KSTtzns --line-directives /tmp/arduino_build_791481/preproc/ctags_target_for_gcc_minus_e.cpp
Compiling sketch...
/home/raspberry/.arduino15/packages/arduino/tools/arm-none-eabi-gcc/4.8.3-2014q1/bin/arm-none-eabi-g++ -mcpu=cortex-m0plus -mthumb -c -g -Os -std=gnu++11 -ffunction-sections -fdata-sections -fno-threadsafe-statics -nostdlib --param max-inline-insns-single=500 -fno-rtti -fno-exceptions -MMD -DF_CPU=48000000L -DARDUINO=10819 -DARDUINO_catwan_usb_stick -DARDUINO_ARCH_SAMD -DCRYSTALLESS -DARDUINO_SAMD_ZERO -D__SAMD21E18A__ -DARM_MATH_CM0PLUS -DUSB_VID=0x1209 -DUSB_PID=0xBAB2 -DUSBCON "-DUSB_MANUFACTURER=\"Electronic Cats\"" "-DUSB_PRODUCT=\"CatWAN USB_Stick\"" -I/home/raspberry/.arduino15/packages/arduino/tools/CMSIS/4.5.0/CMSIS/Include/ -I/home/raspberry/.arduino15/packages/arduino/tools/CMSIS-Atmel/1.2.0/CMSIS/Device/ATMEL/ -I/home/raspberry/.arduino15/packages/electroniccats/hardware/samd/1.2.2/cores/arduino -I/home/raspberry/.arduino15/packages/electroniccats/hardware/samd/1.2.2/variants/catwan_usb_stick -I/home/raspberry/.arduino15/libraries/SerialCommand/src -I/home/raspberry/.arduino15/packages/electroniccats/hardware/samd/1.2.2/libraries/SPI -I/home/raspberry/.arduino15/libraries/LoRa/src /tmp/arduino_build_791481/sketch/final.ino.cpp -o /tmp/arduino_build_791481/sketch/final.ino.cpp.o
Compiling libraries...
Compiling library "SerialCommand"
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

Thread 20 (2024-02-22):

help

S5647787, 2024-02-22:
hi
After uploading my code, I get this information, but I can't find other devices that are in 868 Hz frequency. Can you tell me what changes I need to make for this, or did I do a part of the steps wrong?

Welcome to the LoRa Sniffer CLI 0.2v
09:53:03.461 ->
09:53:03.461 -> With this sketch you can scan the LoRa spectrum
09:53:03.461 -> Changing the Frequency, Spreading Factor, BandWidth or the IQ signals of the radio.
09:53:03.461 -> Type help to get the available commands.
09:53:03.461 -> Electronic Cats ® 2020

AndreaZGuz, 2024-02-22:
Hi @S5647787 !

Thank you for reaching us again.

CatWAN USB Stick helps you to sniff LoRa packets, but it will not show you exactly the devices working in a specific frequency.

If you want to sniff packets, you need to type "set_rx" in the terminal and CatWAN USB Stick will wait for packets to show them in the terminal.
If you want to change the settings of the communication or monitor the parameters set, type "help" in the terminal to see all the available commands.

[Here](https://github.com/ElectronicCats/CatWAN_USB_Stick/wiki/5.-Examples#using-lora-sniffer-tool) is the explanation for using the "set_rx" command to sniff LoRa packets.

I hope the information helps!
If you have further questions, feel free to write to us again.

S5647787, 2024-02-23:
thanks for answering

Closed 2024-02-22.

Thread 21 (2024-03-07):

error

S5647787, 2024-03-07:
hello. I did all the steps to install the board and port, but I get this error, can you help me?

serial manitor: 16:04:42.756 -> Start ScanNetworks on SAMD Zero 16:04:42.756 -> WiFiNINA_Generic v1.8.15-1 16:08:46.166 ->  16:08:46.166 -> Start ScanNetworks on SAMD Zero 16:08:46.166 -> WiFiNINA_Generic v1.8.15-1

output: no device found on COM8
Failed uploading: uploading error: exit status 1

AndreaZGuz, 2024-03-07:
Hi  @S5647787 !

Are you using Arduino IDE? If so, could you please share a screenshot showing the error message and that you have already selected the board?

Thank you!

S5647787, 2024-03-07:
It was working properly until yesterday

13:59:07.344 -> Welcome to the LoRa Sniffer CLI 0.2v
13:59:07.344 ->
13:59:07.344 -> With this sketch you can scan the LoRa spectrum
13:59:07.344 -> Changing the Frequency, Spreading Factor, BandWidth or the IQ signals of the radio.
13:59:07.344 -> Type help to get the available commands.
13:59:07.344 -> Electronic Cats ® 2020

But today I installed the library (wifi nina) and ran this code (#include <WiFi.h>

void setup() {
  Serial.begin(115200);
  delay(1000);
  Serial.println();
  Serial.println("Program start...");

  // Initialize Wi-Fi
  WiFi.begin("YourNetworkSSID", "YourNetworkPassword");
  while (WiFi.status() != WL_CONNECTED) {
    delay(1000);
    Serial.println("Connecting to Wi-Fi...");
  }

  // Print MAC address
  uint8_t mac[6];
  WiFi.macAddress(mac);
  Serial.print("ESP32 MAC Address: ");
  for (int i = 0; i < 6; i++) {
    Serial.print(mac[i], HEX);
    if (i < 5) Serial.print(':');
  }
  Serial.println();
}

void loop() {
  // Your code here
}
)

 and encountered this error

output: no device found on COM8
Failed uploading: uploading error: exit status 1

!
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

AndreaZGuz, 2024-03-08:
Hi @S5647787 !

Thank you for the updates.
Contact us again in case you face again technical issues.

Closed 2024-03-08.

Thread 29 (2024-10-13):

Unable to set Frequence on EU CatWan stick

James-P-D, 2024-10-13:
Hi, I bought an EU CatWan USB device directly from Electronic Cats, and calls to `set_freq` claim to set the frequency correctly, but when I next call `get_freq` or `get_config` it clearly hasn't changed:

```
Connected to COM10 at 9600 baud rate.

get_config
Radio configurations:
Frequency = 902.30 MHz
Bandwidth = 41.7 kHz
Spreading Factor = 6
Coding Rate = 4/5
Sync Word = 0x12
Preamble Length = 8
InvertIQ = disabled
TX Power = 17
Rx active = 0

set_freq 868
Frequency set to 868.00 MHz

get_config
Radio configurations:
Frequency = 902.30 MHz
Bandwidth = 41.7 kHz
Spreading Factor = 6
Coding Rate = 4/5
Sync Word = 0x12
Preamble Length = 8
InvertIQ = disabled
TX Power = 17
Rx active = 0

get_freq
Frequency = 902.30
```

Is there something obvious I'm missing here?

Eric286, 2024-10-14:
Hello @James-P-D

Could you please give me more information about your setup, such as the Arduino version you are using, as well as the CATWAN version you are using, since everything seems to be correct when I tested it, but I want to perform a test with your same configurations to see what could be happening.

The CATWAN version is on the back of the board, it could say USB-Stick 3.1

Have a nice day!

sabas1080, 2024-10-14:
Hi @James-P-D [adjust min/max frequency for RFM95W module](https://github.com/ElectronicCats/CatWAN_USB_Stick/pull/28/commits/93c3afba7ee89de263a5937df6e8f490dc2af737) in pullrequest #28

James-P-D, 2024-10-15:
Hi @sabas1080 and @Eric286 thanks for the quick response!

I've pulled the latest changes and am seeing:
```
LoRaSniffer:6:10: fatal error: Crypto.h: No such file or directory
 #include <Crypto.h>  // Library for cryptographic functions
          ^~~~~~~~~~
compilation terminated.
exit status 1
Crypto.h: No such file or directory

```
I was able to build before pulling, and I've checked the build instructions ( https://github.com/ElectronicCats/CatWAN_USB_Stick/wiki/4.-First-Steps-with-CatWAN-USB-Stick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 ) and there's no mention of a Crypto/AES library.

Of the many cryptographic libraries I can see in Arduino Library Manager, which do I need for the latest update to the firmware?

Eric286, 2024-10-15:
Hello @James-P-D

This is the library used

https://github.com/OperatorFoundation/Crypto

If you have any other errors or questions about the libraries please tell me.

Have a nice Day!

James-P-D, 2024-10-15:
Hi @Eric286 thanks again for the quick response! All working now!
```
get_config
Radio configurations:
Frequency = 915.00 Mhz
Spreading Factor = 7
Bandwidth = 125 Khz
Rx active = 0

set_freq 868
Frequency set to 868.00 Mhz

get_config
Radio configurations:
Frequency = 868.00 Mhz
[...]
```

Many thanks again! And hope you have a good day also!

Closed 2024-10-15.

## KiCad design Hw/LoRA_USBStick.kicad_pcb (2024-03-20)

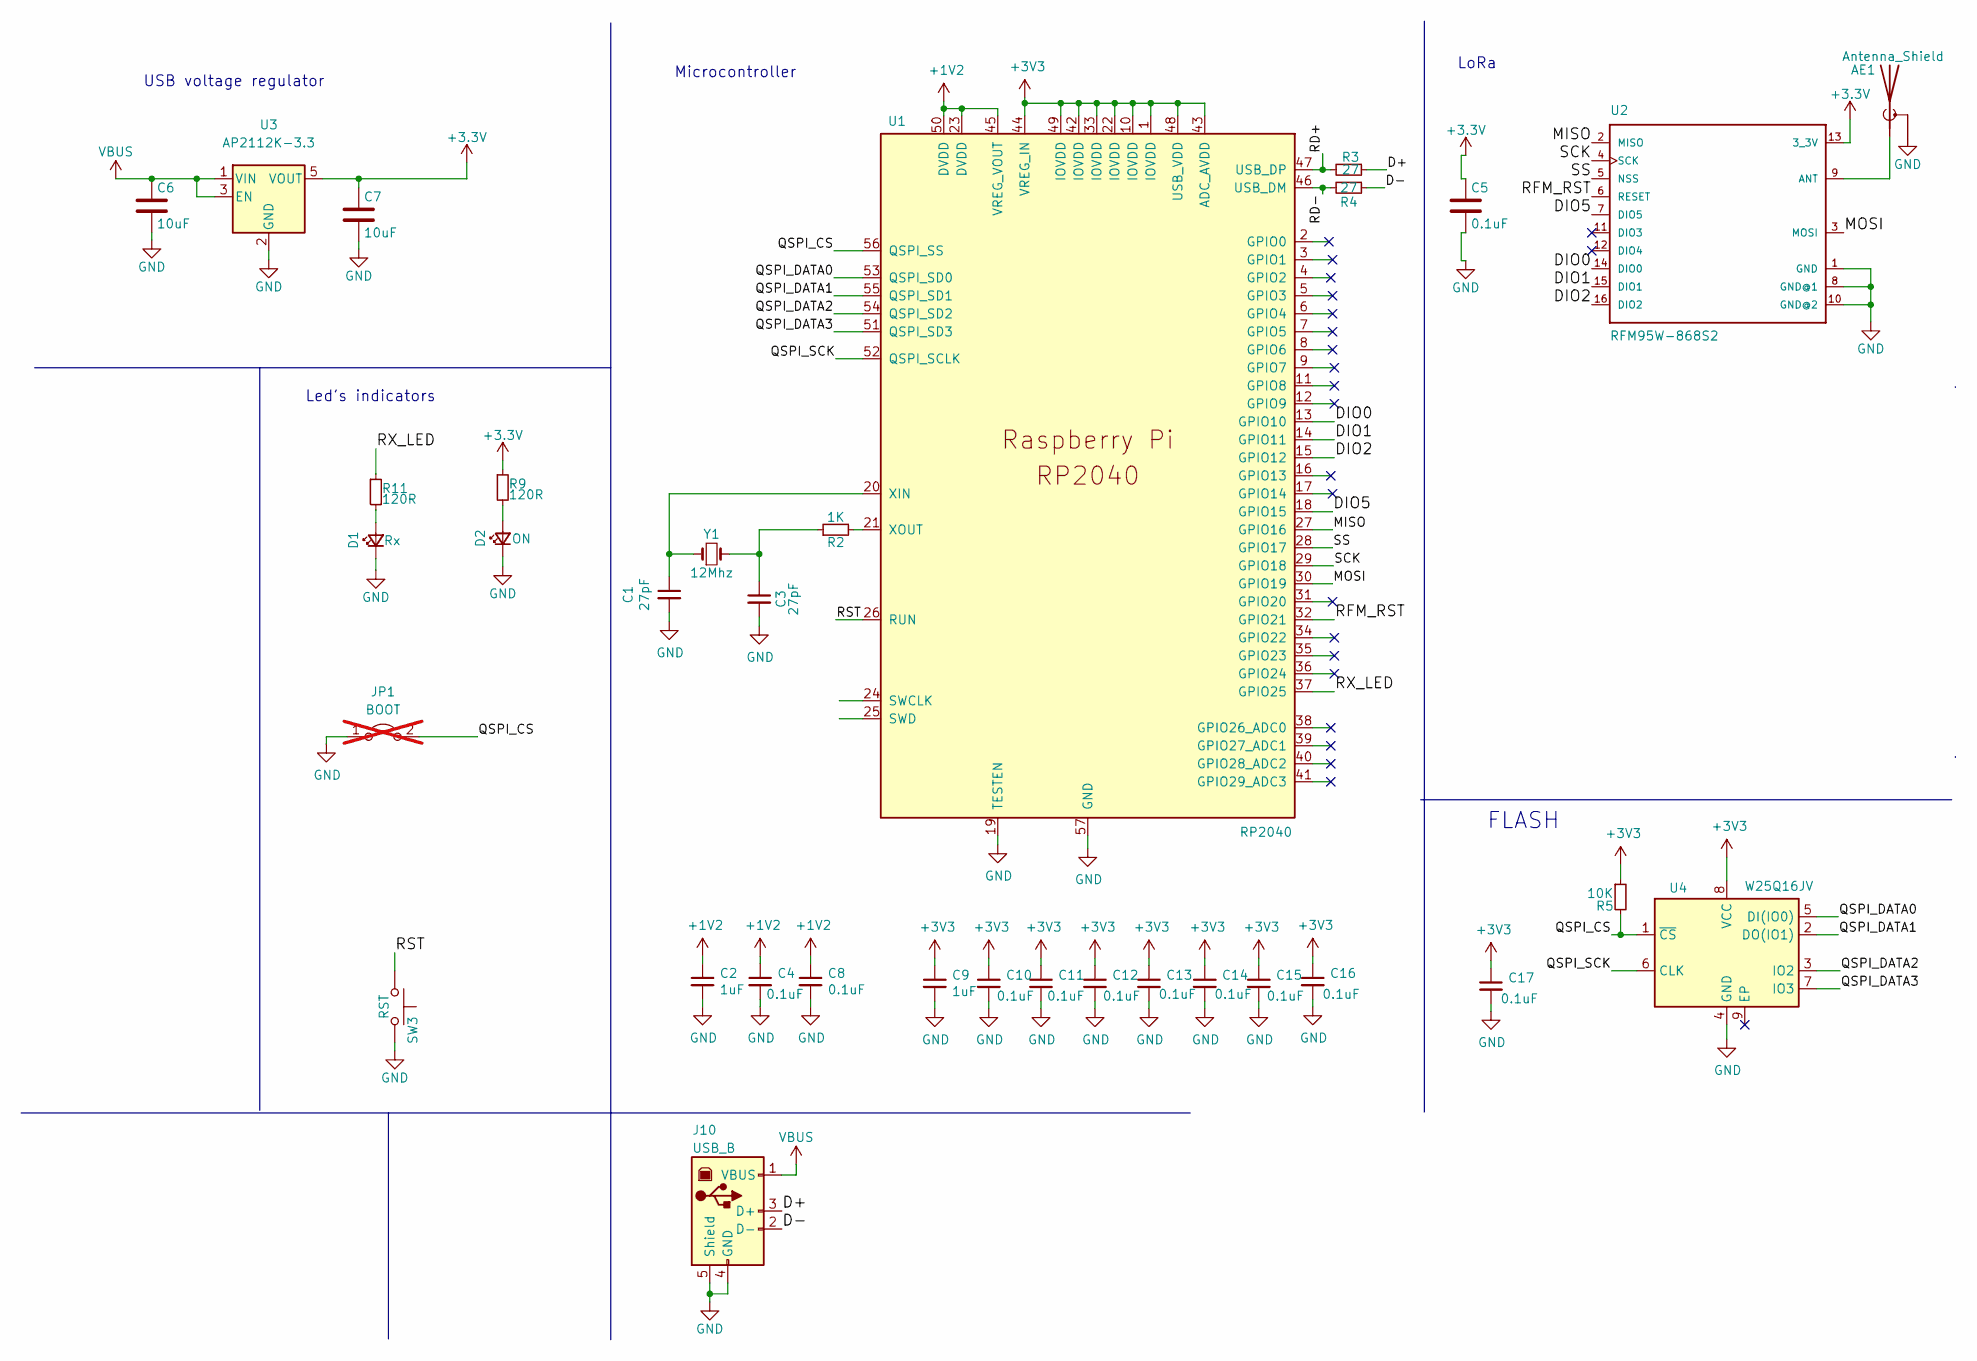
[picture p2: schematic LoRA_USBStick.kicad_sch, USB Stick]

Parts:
AE1: Antenna_Shield; SMA_EDGE; LCSC# C2913580
C1, C3: 27pF; C_0603_1608Metric
C2, C9: 1uF; C_0603_1608Metric; LCSC# C711096
C4, C8, C10, C11, C12, C13, C14, C15, C16, C17: 0.1uF; C_0603_1608Metric; LCSC# C282519
C5: 0.1uF; C_0805_2012Metric_Pad1.15x1.40mm_HandSolder
C6, C7: 10uF; C_0805_2012Metric_Pad1.15x1.40mm_HandSolder; LCSC# C1713
D1: Rx; LED_0805_2012Metric_Pad1.15x1.40mm_HandSolder
D2: ON; LED_0805_2012Metric_Pad1.15x1.40mm_HandSolder
J10: USB_B; C46394; LCSC# C46394
JP1: BOOT; SolderJumper-2_P1.3mm_Open_Pad1.0x1.5mm; not fitted
R2: 1K; R_0603_1608Metric; LCSC# C21190
R3, R4: 27; R_0603_1608Metric; LCSC# C2907136
R5: 10K; R_0603_1608Metric; LCSC# C2930027
R9, R11: 120R; R_0603_1608Metric
SW3: RST; C455281
U1: RP2040; RP2040-QFN-56; LCSC# C2040
U2: RFM95W-868S2; HOPERF_RFM9XW_SMD
U3: AP2112K-3.3; SOT-23-5
U4: W25Q16JV; W25Q16JVUUIQ
Y1: 12Mhz; Crystal_SMD_5032-2Pin_5.0x3.2mm

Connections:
+1V2: C2.1, C4.1, C8.1, U1.23 (DVDD), U1.45 (VREG_VOUT), U1.50 (DVDD)
/D+: J10.3 (D+), R3.1
/D-: J10.2 (D-), R4.1
/DIO0: U1.13 (GPIO10), U2.14 (DIO0)
/DIO1: U1.14 (GPIO11), U2.15 (DIO1)
/DIO2: U1.15 (GPIO12), U2.16 (DIO2)
/DIO5: U1.18 (GPIO15), U2.7 (DIO5)
/MISO: U1.27 (GPIO16), U2.2 (MISO)
/MOSI: U1.30 (GPIO19), U2.3 (MOSI)
/QSPI_CS: JP1.2 (B), R5.2, U1.56 (QSPI_SS), U4.1 (~CS)
/QSPI_DATA0: U1.53 (QSPI_SD0), U4.5 (DI(IO0))
/QSPI_DATA1: U1.55 (QSPI_SD1), U4.2 (DO(IO1))
/QSPI_DATA2: U1.54 (QSPI_SD2), U4.3 (IO2)
/QSPI_DATA3: U1.51 (QSPI_SD3), U4.7 (IO3)
/QSPI_SCK: U1.52 (QSPI_SCLK), U4.6 (CLK)
/RD+: R3.2, U1.47 (USB_DP)
/RD-: R4.2, U1.46 (USB_DM)
/RFM_RST: U1.32 (GPIO21), U2.6 (RESET)
/RST: SW3.1, U1.26 (RUN)
/RX_LED: R11.1, U1.37 (GPIO25)
/SCK: U1.29 (GPIO18), U2.4 (SCK)
/SS: U1.28 (GPIO17), U2.5 (NSS)
GND: AE1.2 (Shield), C1.2, C2.2, C3.2, C4.2, C5.2, C6.2, C7.2, C8.2, C9.2, C10.2, C11.2, C12.2, C13.2, C14.2, C15.2, C16.2, C17.2, D1.1 (K), D2.1 (K), J10.4 (GND), J10.5 (Shield), JP1.1 (A), SW3.2, U1.19 (TESTEN), U1.57 (GND), U2.1 (GND), U2.8 (GND@1), U2.10 (GND@2), U3.2 (GND), U4.4 (GND)
unnamed: AE1.1 (A), U2.9 (ANT)
unnamed: C1.1, U1.20 (XIN), Y1.1
unnamed: C3.1, R2.1, Y1.2
unnamed: D1.2 (A), R11.2
unnamed: D2.2 (A), R9.2
unnamed: R2.2, U1.21 (XOUT)
VBUS: C6.1, J10.1 (VBUS), U3.1 (VIN), U3.3 (EN)

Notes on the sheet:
Led's indicators
LoRa
Microcontroller
USB voltage regulator
FLASH

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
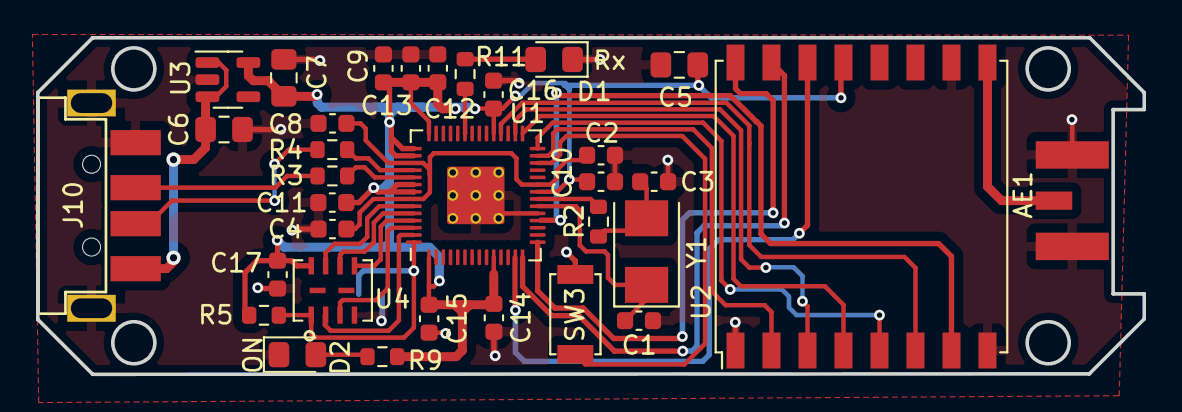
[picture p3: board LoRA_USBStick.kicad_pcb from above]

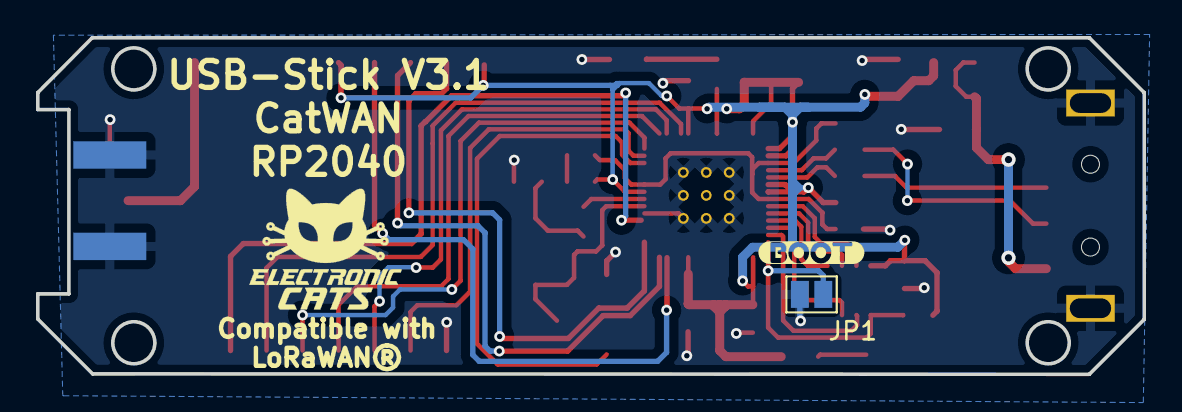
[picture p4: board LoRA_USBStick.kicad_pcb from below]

Board: 2 copper layers, 61.5 x 18.7 mm, 35 parts (2 on the bottom side), 31 nets.

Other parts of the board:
kibuzzard-62D459CC: G***; kibuzzard-62D459CC

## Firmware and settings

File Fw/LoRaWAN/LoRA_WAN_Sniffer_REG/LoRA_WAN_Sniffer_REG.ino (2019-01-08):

#include <SPI.h>

#define DIO0 RFM_DIO0
#define NSS  SS

void RFM_NSS(bool);
int Message=0;
unsigned int Frame_Counter_Tx = 0x0000;
int serialData;

static const unsigned char PROGMEM S_Table[16][16] = {
  {0x63,0x7C,0x77,0x7B,0xF2,0x6B,0x6F,0xC5,0x30,0x01,0x67,0x2B,0xFE,0xD7,0xAB,0x76},
  {0xCA,0x82,0xC9,0x7D,0xFA,0x59,0x47,0xF0,0xAD,0xD4,0xA2,0xAF,0x9C,0xA4,0x72,0xC0},
  {0xB7,0xFD,0x93,0x26,0x36,0x3F,0xF7,0xCC,0x34,0xA5,0xE5,0xF1,0x71,0xD8,0x31,0x15},
  {0x04,0xC7,0x23,0xC3,0x18,0x96,0x05,0x9A,0x07,0x12,0x80,0xE2,0xEB,0x27,0xB2,0x75},
  {0x09,0x83,0x2C,0x1A,0x1B,0x6E,0x5A,0xA0,0x52,0x3B,0xD6,0xB3,0x29,0xE3,0x2F,0x84},
  {0x53,0xD1,0x00,0xED,0x20,0xFC,0xB1,0x5B,0x6A,0xCB,0xBE,0x39,0x4A,0x4C,0x58,0xCF},
  {0xD0,0xEF,0xAA,0xFB,0x43,0x4D,0x33,0x85,0x45,0xF9,0x02,0x7F,0x50,0x3C,0x9F,0xA8},
  {0x51,0xA3,0x40,0x8F,0x92,0x9D,0x38,0xF5,0xBC,0xB6,0xDA,0x21,0x10,0xFF,0xF3,0xD2},
  {0xCD,0x0C,0x13,0xEC,0x5F,0x97,0x44,0x17,0xC4,0xA7,0x7E,0x3D,0x64,0x5D,0x19,0x73},
  {0x60,0x81,0x4F,0xDC,0x22,0x2A,0x90,0x88,0x46,0xEE,0xB8,0x14,0xDE,0x5E,0x0B,0xDB},
  {0xE0,0x32,0x3A,0x0A,0x49,0x06,0x24,0x5C,0xC2,0xD3,0xAC,0x62,0x91,0x95,0xE4,0x79},
  {0xE7,0xC8,0x37,0x6D,0x8D,0xD5,0x4E,0xA9,0x6C,0x56,0xF4,0xEA,0x65,0x7A,0xAE,0x08},
  {0xBA,0x78,0x25,0x2E,0x1C,0xA6,0xB4,0xC6,0xE8,0xDD,0x74,0x1F,0x4B,0xBD,0x8B,0x8A},
  {0x70,0x3E,0xB5,0x66,0x48,0x03,0xF6,0x0E,0x61,0x35,0x57,0xB9,0x86,0xC1,0x1D,0x9E},
  {0xE1,0xF8,0x98,0x11,0x69,0xD9,0x8E,0x94,0x9B,0x1E,0x87,0xE9,0xCE,0x55,0x28,0xDF},
  {0x8C,0xA1,0x89,0x0D,0xBF,0xE6,0x42,0x68,0x41,0x99,0x2D,0x0F,0xB0,0x54,0xBB,0x16}
};


unsigned char NwkSkey[16] = { 0x41, 0xe2, 0xc1, 0x11, 0xcf, 0x0b, 0xfb, 0x8d, 0x1d, 0x08, 0x98, 0xf0, 0xca, 0xa8, 0x77, 0x62 };
unsigned char AppSkey[16] = { 0x6e, 0x9b, 0x51, 0x67, 0x09, 0x92, 0xc2, 0x40, 0xac, 0x1c, 0xf4, 0xe2, 0x38, 0x9c, 0x8d, 0xf2 };
unsigned char DevAddr[4] = { 0x00, 0x00, 0x00, 0x07 };
unsigned char data[100];


void RFM_Message(){
  Message=1;
  }

void setup() {
  SPI.setDataMode(SPI_MODE0);
  Serial.begin(115200);
  while(!Serial);
  SPI.begin();

  pinMode(NSS, OUTPUT);
  pinMode(DIO0, INPUT);
  digitalWrite(NSS, HIGH);

  Serial.println("Inciando");
  //Initialize RFM module
  
  RFM_Init();
  RFM_Continuous_Receive();
}

void loop() {
  if(Message){
    Serial.println("Rx:");
    unsigned char RFM_Package_Location = 0x00;
    unsigned char RFM_Rx_Length = 0x00;
    if((RFM_Read(0x12) & 0x20) != 0x20){
      Serial.println("CRC Ok");
    }
    else{
      Serial.println("CRC No Ok");
    }
    RFM_Package_Location = RFM_Read(0x10); //Read start position of received package
    RFM_Rx_Length = RFM_Read(0x13);      //Read length of received package
    RFM_Write(0x0D,RFM_Package_Location); //Set SPI pointer to start of package
    for (unsigned char i = 0x00; i < RFM_Rx_Length; i++){
      data[i] = RFM_Read(0x00);
      Serial.print("Dato ");
      Serial.print(i);
      Serial.print(": ");
      Serial.println(data[i],HEX);
     }
     Message=0; 
     RFM_Write(0x12, 0xFF); //Clear interrupts
  }
  
  if (Serial.available()) {
   serialData= Serial.read();
   }
   if(serialData=='1'){ 
    uint16_t temp;
    uint8_t Data[2];
    uint8_t Data_Length = 0x02;

    temp = 50;
    Data[0] = (temp >> 8) & 0xff;
    Data[1] = temp & 0xff;

    LORA_Send_Data(Data, Data_Length, Frame_Counter_Tx);
    Frame_Counter_Tx++;
    Serial.println("Dato enviado");
    // reset sleep count
    //sleep_count = 0;
    serialData=0;
   }
   else if(serialData=='2'){
    Serial.print("Status: ");
    Serial.println(RFM_Read(0x18),HEX);
    Serial.print("IRQ: ");
    Serial.println(RFM_Read(0x12),HEX);
    Serial.print("Bytes of payload: ");
    Serial.println(RFM_Read(0x13),HEX);
    Serial.print("Valid headers received: ");
    Serial.print(RFM_Read(0x14),HEX);
    Serial.println(RFM_Read(0x14),HEX);
    Serial.print("Mensaje: ");
    Serial.println(Message);
    Serial.print("OpMode: ");
    Serial.println(RFM_Read(0x01),HEX);
    serialData=0;
    delay(100);
    }
  

}

/*
*****************************************************************************************
* Description: Function used to initialize the RFM module on startup
*****************************************************************************************
*/
void RFM_Init()
{ 
  int ver = RFM_Read(0x42);
  if(ver==18){
  Serial.print("SX1276 or RFM95 detected ");
  }
  else{
    Serial.println("Error detecting RFM");
    Serial.println("Check your connections");
    while(true);
  }
  //Switch RFM to sleep
  RFM_Write(0x01,0x00);

  //Set RFM in LoRa mode
  RFM_Write(0x01,0x80);
  //Set RFM in Standby mode wait on mode ready
  RFM_Write(0x01,0x81);
  
  delay(50);
  
  //Set carrair frequency
  // 868.100 MHz / 61.035 Hz = 14222987 = 0xD9068B
  // 904.400 Mhz / 61.035 Hz = 14866880 = 0xE2D9C0
  // 912.500 Mhz / 61.035 Hz = 14950438 = 0xE42026
  // 902.300 Mhz / 61.035 Hz = 14783321 = 0xE19359
  RFM_Write(0x06,0xE1);
  RFM_Write(0x07,0x93);
  RFM_Write(0x08,0x59);
  
  //PA pin (minimal power)
  RFM_Write(0x09,0xFF);

  //Switch LNA boost on
  //RFM_Write(0x0C,0x23);
  
  RFM_Write(0x1E,0xB4); //SF7 CRC On
  RFM_Write(0x1D,0x72); //125 kHz 4/5 coding rate explicit header mode
  RFM_Write(0x26,0x0C); //Low datarate optimization off AGC auto on 
  //Rx Timeout set to 37 symbols
  RFM_Write(0x1F,0x25);

  //Preamble length set to 8 symbols
  //0x0008 + 4 = 12
  RFM_Write(0x20,0x00);
  RFM_Write(0x21,0x08);

  //Set LoRa sync word
  RFM_Write(0x39,0x34);

  //Set IQ to normal values
  RFM_Write(0x33,0x27);
  RFM_Write(0x3B,0x1D);

  //Set FIFO pointers
  //TX base adress
  RFM_Write(0x0E,0x80);
  //Rx base adress
  RFM_Write(0x0F,0x00);

  //Switch RFM to sleep
  RFM_Write(0x01,0x00);
  Serial.println("Configured");
}



/*
*****************************************************************************************
* Description : Function for change just the bits of operation mode
*
* Arguments   : mode just use the 3 first bits
*               X000 = Sleep mode
*               X001 = Stdby mode
*               X010 = FS mode TX (FSTx)
*               X011 = Transmitter mode (Tx)
*               X100 = FS mode RX (FSRx) 
*               X101 = Receiver continuous mode
*               x110 = Receiver single mode
*               x111 = Channel activity detection
*****************************************************************************************
*/
void RFM_OpMode (int mode) {
    RFM_Write(0x01, 0x80 | mode); //
}


/*
*****************************************************************************************
* Description : Function to switch RFM to continuous receive mode, used for Class C 
*****************************************************************************************
*/
void RFM_Continuous_Receive(void)
{
  attachInterrupt(0, RFM_Message, RISING);
  //Clear all interrupts
  //RFM_Write(0x12, 0xFF);
  //Change DIO 0 back to RxDone
  RFM_Write(0x40,0x00);

  //Invert IQ Back
  RFM_Write(0x33,0x67);
  RFM_Write(0x3B,0x19);
  
  //Change Datarate
  RFM_Write(0x1E,0xA4); //SF10 CRC On
  RFM_Write(0x1D,0x72); //125 kHz 4/5 coding rate explicit header mode
  RFM_Write(0x26,0x04); //Low datarate optimization off AGC auto on

  //Set Hop frequency Period to 0
  RFM_Write(0x24,0x00);
  
  //Set carrair frequency
  // 904.400 Mhz / 61.035 Hz = 14866880 = 0xE2D9C0
  // 912.500 Mhz / 61.035 Hz = 14950438 = 0xE42026
  // 902.300 Mhz / 61.035 Hz = 14783321 = 0xE19359
  // 923.300 Mhz / 61.035 Hz = 15127386 = 0xE6D35A . 
  RFM_Write(0x06,0xE6);
  RFM_Write(0x07,0xD3);
  RFM_Write(0x08,0x5A);

  //Switch to continuous receive
  //Set operation mode to Rx continuous
  RFM_Write(0x01,0x85); 
  delay(50);

}




/*
*****************************************************************************************
* Description : Function contstructs a LoRaWAN package and sends it
*
* Arguments   : *Data pointer to the array of data that will be transmitted
*               Data_Length nuber of bytes to be transmitted
*               Frame_Counter_Up  Frame counter of upstream frames
*****************************************************************************************
*/
void LORA_Send_Data(unsigned char *Data, unsigned char Data_Length, unsigned int Frame_Counter_Tx)
{
  //Define variables
  unsigned char i;

  //Direction of frame is up
  unsigned char Direction = 0x00;

  unsigned char RFM_Data[64];
  unsigned char RFM_Package_Length;

  unsigned char MIC[4];

  //Unconfirmed data up
  unsigned char Mac_Header = 0x40;

  unsigned char Frame_Control = 0x00;
  unsigned char Frame_Port = 0x01;

  //Encrypt the data
  Encrypt_Payload(Data, Data_Length, Frame_Counter_Tx, Direction);


  //Build the Radio Package
  RFM_Data[0] = Mac_Header;

  RFM_Data[1] = DevAddr[3];
  RFM_Data[2] = DevAddr[2];
  RFM_Data[3] = DevAddr[1];
  RFM_Data[4] = DevAddr[0];

  RFM_Data[5] = Frame_Control;

  RFM_Data[6] = (Frame_Counter_Tx & 0x00FF);
  RFM_Data[7] = ((Frame_Counter_Tx >> 8) & 0x00FF);

  RFM_Data[8] = Frame_Port;

  //Set Current package length
  RFM_Package_Length = 9;

  //Load Data
  for(i = 0; i < Data_Length; i++)
  {
    RFM_Data[RFM_Package_Length + i] = Data[i];
  }

  //Add data Lenth to package length
  RFM_Package_Length = RFM_Package_Length + Data_Length;

  //Calculate MIC
  Calculate_MIC(RFM_Data, MIC, RFM_Package_Length, Frame_Counter_Tx, Direction);

  //Load MIC in package
  for(i = 0; i < 4; i++)
  {
    RFM_Data[i + RFM_Package_Length] = MIC[i];
  }

  //Add MIC length to RFM package length
  RFM_Package_Length = RFM_Package_Length + 4;

  //Send Package
  RFM_Send_Package(RFM_Data, RFM_Package_Length);
}


/*
*****************************************************************************************
* Description : Function for sending a package with the RFM
*
* Arguments   : *RFM_Tx_Package Pointer to arry with data to be send
*               Package_Length  Length of the package to send
*****************************************************************************************
*/

void RFM_Send_Package(unsigned char *RFM_Tx_Package, unsigned char Package_Length)
{
  detachInterrupt(0);
  unsigned char i;
  unsigned char RFM_Tx_Location = 0x00;
  
  //Set RFM in Standby mode wait on mode ready
  RFM_Write(0x01,0x81);
  //Clear all interrupts
  RFM_Write(0x12, 0xFF);
  while (digitalRead(DIO5) == LOW)
  {
    Serial.print(".");
  }

  
  delay(10);
  
  //Change DIO mapping to TxDone
  //Switch DIO0 to TxDone
  RFM_Write(0x40,0x40);

  //Set carrier frequency
  // 868.100 MHz / 61.035 Hz = 14222987 = 0xD9068B
  // 904.400 Mhz / 61.035 Hz = 14866880 = 0xE2D9C0
  // 912.500 Mhz / 61.035 Hz = 14950438 = 0xE42026
  // 902.300 Mhz / 61.035 Hz = 14783321 = 0xE19359
  RFM_Write(0x06,0xE4);
  RFM_Write(0x07,0x20);
  RFM_Write(0x08,0x26);

  //SF7 BW 125 kHz
  RFM_Write(0x1E,0x74); //SF7 CRC On
  RFM_Write(0x1D,0x72); //125 kHz 4/5 coding rate explicit header mode
  RFM_Write(0x26,0x04); //Low datarate optimization off AGC auto on

  //Set IQ to normal values
  RFM_Write(0x33,0x27);
  RFM_Write(0x3B,0x1D);

  //Set payload length to the right length
  RFM_Write(0x22,Package_Length);

  //Set SPI pointer to start of Tx part in FiFo
  //RFM_Write(0x0D,RFM_Tx_Location);
  RFM_Write(0x0D,0x80); // hardcoded fifo location according RFM95 specs

  //Write Payload to FiFo
  for (i = 0;i < Package_Length; i++)
  {
    RFM_Write(0x00,*RFM_Tx_Package);
    RFM_Tx_Package++;
  }

  //Switch RFM to Tx
  RFM_Write(0x01,0x83);

  //Wait for TxDone
  while(digitalRead(DIO0) == LOW)
  {
    //Serial.print(".");
  }
  
  Serial.println();
  Serial.print("Dato enviado TxDone: ");
  Serial.println(RFM_Read(0x12),HEX);
  Serial.println();
  //Clear all RegIrqFlags 
  RFM_Write(0x12, 0xFF); 
  //Switch RFM to Rx contuously
  RFM_Continuous_Receive();
  Message=0;
}


/*
*****************************************************************************************
* Description : Funtion that toggle the NSS and configure the SPI
*
* Arguments   : val is the state of the NSS you want to write
*               to start or finish a the communication
*****************************************************************************************
*/
void RFM_NSS(bool val){
  if (!val)
        SPI.beginTransaction(SPISettings(1E6, MSBFIRST, SPI_MODE0));
    else
        SPI.endTransaction();
    digitalWrite(NSS, val);
  
  }


/*
*****************************************************************************************
* Description : Funtion that writes a register from the RFM
*
* Arguments   : RFM_Address Address of register to be written
*         RFM_Data    Data to be written
*****************************************************************************************
*/
void RFM_Write(unsigned char RFM_Address, unsigned char RFM_Data)
{
  //Set NSS pin Low to start communication
  //digitalWrite(NSS,LOW);
  RFM_NSS(0);

  //Send Addres with MSB 1 to make it a writ command
  SPI.transfer(RFM_Address | 0x80);
  //Send Data
  SPI.transfer(RFM_Data);

  //Set NSS pin High to end communication
  RFM_NSS(1);
  //digitalWrite(NSS,HIGH);
}

/*
*****************************************************************************************
* Description : Funtion that reads a register from the RFM
*
* Arguments   : RFM_Address Address of register to be read
*****************************************************************************************
*/
int RFM_Read(int addr) {
    RFM_NSS(0);
    SPI.transfer(addr & 0x7F);
    int val = SPI.transfer(0x00);
    RFM_NSS(1);
    return val;
}




/*
*****************************************************************************************
* Description : Function to know the status of the LoRA Modem on the Rx time 
*               It may return 5 bits:  
*                                    4 - Modem clear 
*                                    3 - Header info calid
*                                    2 - Rx on-going
*                                    1 - Signal synchronized
*                                    0 - Signal detected
*****************************************************************************************
*/
int RFM_Status(void){
  return RFM_Read(0x18)&0x1F;
  }




/******************************************Starts AES shit**********************************************/



void Encrypt_Payload(unsigned char *Data, unsigned char Data_Length, unsigned int Frame_Counter, unsigned char Direction)
{
  unsigned char i = 0x00;
  unsigned char j;
  unsigned char Number_of_Blocks = 0x00;
  unsigned char Incomplete_Block_Size = 0x00;

  unsigned char Block_A[16];

  //Calculate number of blocks
  Number_of_Blocks = Data_Length / 16;
  Incomplete_Block_Size = Data_Length % 16;
  if(Incomplete_Block_Size != 0)
  {
    Number_of_Blocks++;
  }

  for(i = 1; i <= Number_of_Blocks; i++)
  {
    Block_A[0] = 0x01;
    Block_A[1] = 0x00;
    Block_A[2] = 0x00;
    Block_A[3] = 0x00;
    Block_A[4] = 0x00;

    Block_A[5] = Direction;

    Block_A[6] = DevAddr[3];
    Block_A[7] = DevAddr[2];
    Block_A[8] = DevAddr[1];
    Block_A[9] = DevAddr[0];

    Block_A[10] = (Frame_Counter & 0x00FF);
    Block_A[11] = ((Frame_Counter >> 8) & 0x00FF);

    Block_A[12] = 0x00; //Frame counter upper Bytes
    Block_A[13] = 0x00;

    Block_A[14] = 0x00;

    Block_A[15] = i;

    //Calculate S
    AES_Encrypt(Block_A,AppSkey); //original


    //Check for last block
    if(i != Number_of_Blocks)
    {
      for(j = 0; j < 16; j++)
      {
        *Data = *Data ^ Block_A[j];
        Data++;
      }
    }
    else
    {
      if(Incomplete_Block_Size == 0)
      {
        Incomplete_Block_Size = 16;
      }
      for(j = 0; j < Incomplete_Block_Size; j++)
      {
        *Data = *Data ^ Block_A[j];
        Data++;
      }
    }
  }
}

void Calculate_MIC(unsigned char *Data, unsigned char *Final_MIC, unsigned char Data_Length, unsigned int Frame_Counter, unsigned char Direction)
{
  unsigned char i;
  unsigned char Block_B[16];

  unsigned char Key_K1[16] = {
    0x00, 0x00, 0x00, 0x00, 0x00, 0x00, 0x00, 0x00,
    0x00, 0x00, 0x00, 0x00, 0x00, 0x00, 0x00, 0x00
  };
  unsigned char Key_K2[16] = {
    0x00, 0x00, 0x00, 0x00, 0x00, 0x00, 0x00, 0x00,
    0x00, 0x00, 0x00, 0x00, 0x00, 0x00, 0x00, 0x00
  };

  //unsigned char Data_Copy[16];

  unsigned char Old_Data[16] = {
    0x00, 0x00, 0x00, 0x00, 0x00, 0x00, 0x00, 0x00,
    0x00, 0x00, 0x00, 0x00, 0x00, 0x00, 0x00, 0x00
  };
  unsigned char New_Data[16] = {
    0x00, 0x00, 0x00, 0x00, 0x00, 0x00, 0x00, 0x00,
    0x00, 0x00, 0x00, 0x00, 0x00, 0x00, 0x00, 0x00
  };


  unsigned char Number_of_Blocks = 0x00;
  unsigned char Incomplete_Block_Size = 0x00;
  unsigned char Block_Counter = 0x01;

  //Create Block_B
  Block_B[0] = 0x49;
  Block_B[1] = 0x00;
  Block_B[2] = 0x00;
  Block_B[3] = 0x00;
  Block_B[4] = 0x00;

  Block_B[5] = Direction;

  Block_B[6] = DevAddr[3];
  Block_B[7] = DevAddr[2];
  Block_B[8] = DevAddr[1];
  Block_B[9] = DevAddr[0];

  Block_B[10] = (Frame_Counter & 0x00FF);
  Block_B[11] = ((Frame_Counter >> 8) & 0x00FF);

  Block_B[12] = 0x00; //Frame counter upper bytes
  Block_B[13] = 0x00;

  Block_B[14] = 0x00;
  Block_B[15] = Data_Length;

  //Calculate number of Blocks and blocksize of last block
  Number_of_Blocks = Data_Length / 16;
  Incomplete_Block_Size = Data_Length % 16;

  if(Incomplete_Block_Size != 0)
  {
    Number_of_Blocks++;
  }

  Generate_Keys(Key_K1, Key_K2);

  //Preform Calculation on Block B0

  //Preform AES encryption
  AES_Encrypt(Block_B,NwkSkey);

  //Copy Block_B to Old_Data
  for(i = 0; i < 16; i++)
  {
    Old_Data[i] = Block_B[i];
  }

  //Preform full calculating until n-1 messsage blocks
  while(Block_Counter < Number_of_Blocks)
  {
    //Copy data into array
    for(i = 0; i < 16; i++)
    {
      New_Data[i] = *Data;
      Data++;
    }

    //Preform XOR with old data
    XOR(New_Data,Old_Data);

    //Preform AES encryption
    AES_Encrypt(New_Data,NwkSkey);

    //Copy New_Data to Old_Data
    for(i = 0; i < 16; i++)
    {
      Old_Data[i] = New_Data[i];
    }

    //Raise Block counter
    Block_Counter++;
  }

  //Perform calculation on last block
  //Check if Datalength is a multiple of 16
  if(Incomplete_Block_Size == 0)
  {
    //Copy last data into array
    for(i = 0; i < 16; i++)
    {
      New_Data[i] = *Data;
      Data++;
    }

    //Preform XOR with Key 1
    XOR(New_Data,Key_K1);

    //Preform XOR with old data
    XOR(New_Data,Old_Data);

    //Preform last AES routine
    // read NwkSkey from PROGMEM
    AES_Encrypt(New_Data,NwkSkey);
  }
  else
  {
    //Copy the remaining data and fill the rest
    for(i =  0; i < 16; i++)
    {
      if(i < Incomplete_Block_Size)
      {
        New_Data[i] = *Data;
        Data++;
      }
      if(i == Incomplete_Block_Size)
      {
        New_Data[i] = 0x80;
      }
      if(i > Incomplete_Block_Size)
      {
        New_Data[i] = 0x00;
      }
    }

    //Preform XOR with Key 2
    XOR(New_Data,Key_K2);

    //Preform XOR with Old data
    XOR(New_Data,Old_Data);

    //Preform last AES routine
    AES_Encrypt(New_Data,NwkSkey);
  }

  Final_MIC[0] = New_Data[0];
  Final_MIC[1] = New_Data[1];
  Final_MIC[2] = New_Data[2];
  Final_MIC[3] = New_Data[3];
}

void Generate_Keys(unsigned char *K1, unsigned char *K2)
{
  unsigned char i;
  unsigned char MSB_Key;

  //Encrypt the zeros in K1 with the NwkSkey
  AES_Encrypt(K1,NwkSkey);

  //Create K1
  //Check if MSB is 1
  if((K1[0] & 0x80) == 0x80)
  {
    MSB_Key = 1;
  }
  else
  {
    MSB_Key = 0;
  }

  //Shift K1 one bit left
  Shift_Left(K1);

  //if MSB was 1
  if(MSB_Key == 1)
  {
    K1[15] = K1[15] ^ 0x87;
  }

  //Copy K1 to K2
  for( i = 0; i < 16; i++)
  {
    K2[i] = K1[i];
  }

  //Check if MSB is 1
  if((K2[0] & 0x80) == 0x80)
  {
    MSB_Key = 1;
  }
  else
  {
    MSB_Key = 0;
  }

  //Shift K2 one bit left
  Shift_Left(K2);

  //Check if MSB was 1
  if(MSB_Key == 1)
  {
    K2[15] = K2[15] ^ 0x87;
  }
}

void Shift_Left(unsigned char *Data)
{
  unsigned char i;
  unsigned char Overflow = 0;
  //unsigned char High_Byte, Low_Byte;

  for(i = 0; i < 16; i++)
  {
    //Check for overflow on next byte except for the last byte
    if(i < 15)
    {
      //Check if upper bit is one
      if((Data[i+1] & 0x80) == 0x80)
      {
        Overflow = 1;
      }
      else
      {
        Overflow = 0;
      }
    }
    else
    {
      Overflow = 0;
    }

    //Shift one left
    Data[i] = (Data[i] << 1) + Overflow;
  }
}

void XOR(unsigned char *New_Data,unsigned char *Old_Data)
{
  unsigned char i;

  for(i = 0; i < 16; i++)
  {
    New_Data[i] = New_Data[i] ^ Old_Data[i];
  }
}
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

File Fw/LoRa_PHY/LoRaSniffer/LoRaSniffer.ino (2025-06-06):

/**
 * Example LoRaSniffer
 * Authors: Eduardo Contreras @ Electronic Cats
 *          Raul Vargas@ Electronic Cats
 *
 * PLEASE REFER TO THESE LIBRARIES:
 *   https://github.com/kroimon/Arduino-SerialCommand
 *   https://github.com/sandeepmistry/arduino-LoRa
 *   https://github.com/OperatorFoundation/Crypto
 *
 * This code is beerware; if you see me (or any other collaborator
 * member) at the local, and you've found our code helpful,
 * please buy us a round!
 * Distributed as-is; no warranty is given.
 */

#define SERIALCOMMAND_HARDWAREONLY

#include <SerialCommand.h>
#include <SPI.h>
#include <LoRa.h>
#include <Crypto.h>
#include <AES.h>

// Initialize AES128 object for encryption
AES128 aes;

// 128-bit encryption key for AES
byte aes_key[16] = { 0x00, 0x01, 0x02, 0x03, 0x04, 0x05, 0x06, 0x07, 0x08, 0x09, 0x0A, 0x0B, 0x0C, 0x0D, 0x0E, 0x0F };
// Initialization vector for AES (not used in this example)
byte aes_iv[16] = { 0x00, 0x00, 0x00, 0x00, 0x00, 0x00, 0x00, 0x00, 0x00, 0x00, 0x00, 0x00, 0x00, 0x00, 0x00, 0x00 };

// Variables for sensor simulation
bool sensorActive = false;
unsigned long lastSendTime = 0;
unsigned long sendInterval = 5000;  // Interval for sending sensor data (5 seconds)

// **New variable to control encryption**
bool encryptionEnabled = false;  // By default, encryption is disabled

#define SS 17
#define RFM_RST 21
#define RFM_DIO0 10
#define RFM_DIO5 15

SerialCommand SCmd;

float fwVersion= 0.2;

float frequency = 915;
int spreadFactor = 7;
int bwReference = 7;
int codingRate = 5;
byte syncWord = 0x12;
int preambleLength = 8;
int txPower = 17;
int channel = 0;
bool rx_status = false;
int inv_iq = 0;

void setup(){
  pinMode(LED_BUILTIN,OUTPUT);      // Configure the onboard LED for output
  digitalWrite(LED_BUILTIN,LOW);    // default to LED off
  pinMode(RFM_DIO5,INPUT);
  Serial.begin(115200);
  while (!Serial);

  Serial.println("Welcome to the LoRa Sniffer CLI " + String(fwVersion,1) + "v\n");
  Serial.println("With this sketch you can scan the LoRa spectrum");
  Serial.println("Changing the Frequency, Spreading Factor, BandWidth or the IQ signals of the radio.");
  Serial.println("Type help to get the available commands.");
  Serial.println("Electronic Cats ® 2020");

  // Set AES encryption key
  aes.setKey(aes_key, sizeof(aes_key));

  // Setup callbacks for SerialCommand commands
  SCmd.addCommand("help",help);
  SCmd.addCommand("set_rx",set_rx);
  SCmd.addCommand("set_tx",set_tx);
  SCmd.addCommand("set_tx_hex",set_tx_hex);
  SCmd.addCommand("set_tx_ascii",set_tx_ascii);
  SCmd.addCommand("set_freq",set_freq);
  SCmd.addCommand("set_sf",set_sf);
  SCmd.addCommand("set_bw",set_bw);
  SCmd.addCommand("set_cr",set_cr);
  SCmd.addCommand("set_sw",set_sw);
  SCmd.addCommand("set_pl",set_pl);
  SCmd.addCommand("set_tp",set_tp);
  SCmd.addCommand("set_chann",set_chann);
  SCmd.addCommand("set_inv_iq",set_inv_iq);

  SCmd.addCommand("get_config",get_config);
  SCmd.addCommand("get_freq",get_freq);
  SCmd.addCommand("get_sf",get_sf);
  SCmd.addCommand("get_bw",get_bw);
  SCmd.addCommand("get_cr",get_cr);
  SCmd.addCommand("get_sw",get_sw);
  SCmd.addCommand("get_pl",get_pl);
  SCmd.addCommand("get_tp",get_tp);

  SCmd.addCommand("set_sensor", set_sensor);  // Command to start the sensor simulation

  // **New command to enable/disable encryption**
  SCmd.addCommand("set_encryption", set_encryption);

  SCmd.setDefaultHandler(unrecognized);  // Handler for command that isn't matched  (says "What?")

  LoRa.setPins(SS, RFM_RST, RFM_DIO0);

  if (!LoRa.begin(915E6)) {
    Serial.println("Starting LoRa failed!");
    while (1); // Stop execution if LoRa initialization fails
  }

  //LoRa.setFrequency(915E6);
  LoRa.setSpreadingFactor(spreadFactor);
  //LoRa.setSignalBandwidth(125E3);
  LoRa.setCodingRate4(codingRate);
  //LoRa.setSyncWord(0x12);
  LoRa.setSyncWord(syncWord);
  //LoRa.setPreambleLength(8);
  LoRa.setPreambleLength(preambleLength);

  rx_status = false;

  // Set the callback function to handle incoming packets
  LoRa.onReceive(onReceive);
}

void loop()
{
  SCmd.readSerial();     // We don't do much, just process serial commands

  // Sensor simulation: send encrypted data at regular intervals
  if (sensorActive && (millis() - lastSendTime >= sendInterval)) {
    lastSendTime = millis();  // Update the last send time

    // Generate random sensor data
    int randomValue = random(0, 255);
    Serial.print("Data before encryption (decimal): ");
    Serial.println(randomValue);

    byte plainText[16] = { 0 };
    sprintf((char *)plainText, "%02X", randomValue);  // Convert to hexadecimal

    byte encryptedText[16] = { 0 };

    // **Check if encryption is enabled before encrypting**
    if (encryptionEnabled) {
      aes.encryptBlock(encryptedText, plainText);  // Encrypt the data
      Serial.println("Encryption enabled, sending encrypted data.");
    } else {
      memcpy(encryptedText, plainText, sizeof(plainText));  // Send plain data
      Serial.println("Encryption disabled, sending plain data.");
    }

    // Send the (possibly encrypted) data over LoRa
    LoRa.beginPacket();
    LoRa.write(encryptedText, sizeof(encryptedText));
    LoRa.endPacket();

    Serial.println("Data sent successfully!");
  }
}

void help(){
  Serial.println("Fw version: " + String(fwVersion,1)+"v");
  Serial.println("\tConfiguration commands:");
  Serial.println("\tset_rx");
  Serial.println("\tset_tx");
  Serial.println("\tset_tx_hex");
  Serial.println("\tset_tx_ascii");
  Serial.println("\tset_chann");
  Serial.println("\tset_freq");
  Serial.println("\tset_sf");
  Serial.println("\tset_bw");
  Serial.println("\tset_cr");
  Serial.println("\tset_sw");
  Serial.println("\tset_pl");
  Serial.println("\tset_tp");
  Serial.println("\tset_inv_iq");

  Serial.println("Monitor commands:");
  Serial.println("\tget_freq");
  Serial.println("\tget_sf");
  Serial.println("\tget_bw");
  Serial.println("\tget_cr");
  Serial.println("\tget_sw");
  Serial.println("\tget_pl");
  Serial.println("\tget_tp");

  Serial.println("\tget_config");

  Serial.println("Type 'set_sensor-on/off' to simulate sensor data transmission.");
  Serial.println("Type 'set_encryption-on/off' to enable or disable data encryption.");

  Serial.println("..help");

}

// **New command to enable/disable encryption**
void set_encryption() {
  char *arg = SCmd.next();
  if (arg != NULL) {
    if (strcmp(arg, "on") == 0) {
      encryptionEnabled = true;
      Serial.println("Encryption enabled.");
    } else if (strcmp(arg, "off") == 0) {
      encryptionEnabled = false;
      Serial.println("Encryption disabled.");
    } else {
      Serial.println("Invalid argument. Use 'on' or 'off'.");
    }
  } else {
    Serial.println("No argument. Use 'on' or 'off'.");
  }
}
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

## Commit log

2018-07-02 Add project
    [LoRA_USBStick.kicad_pcb, LoRA_USBStick.sch]
2018-07-03 Add gerbers
    [LoRA_USBStick-B.Cu.gbl, LoRA_USBStick-B.Mask.gbs, LoRA_USBStick-B.Paste.gbp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]
2018-07-10 fix gerber
    [LoRA_USBStick-B.Cu.gbl, LoRA_USBStick-B.Mask.gbs, LoRA_USBStick-B.Paste.gbp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]
2018-07-29 Add Arduino instruction
2018-08-08 Update kicad 5
    [LoRA_USBStick-2018-07-25-13-47-18.sch, LoRA_USBStick.csv, LoRA_USBStick.kicad_pcb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]
2018-08-08 add relay compatibility firmware
2018-08-21 Update measure for case
    [LoRA_USBStick.kicad_pcb, LoRA_USBStick.sch]
2018-09-19 remove gerbers with logo electroniccats
2018-09-19 Fix notes text
    [LoRA_USBStick.kicad_pcb]
2018-11-06 Change USB side version 1.1v
    [LoRA_USBStick.kicad_pcb]
2018-11-25 Clean GPIO not use
    [LoRA_USBStick.sch]
2018-11-26 Remove TX and RX not used
    [LoRA_USBStick.sch]
2018-11-28 Fix vias on PCB
    [LoRA_USBStick.kicad_pcb]
2019-01-08 Add v2.0
    [LoRA_USBStick.kicad_pcb]
2019-04-07 add DIO5 support fix functions
    [LoRaSniffer.ino]
2019-05-27 add pin table
2019-05-27 Fix pin table
2019-05-28 Fix traces v2.3
    [LoRA_USBStick.kicad_pcb]
2020-01-09 Update board 2.4v
    [LoRA_USBStick.kicad_pcb, LoRA_USBStick.sch]
2020-01-09 Update version
    [LoRA_USBStick.kicad_pcb, LoRA_USBStick.sch]
2020-01-09 hide cupper zones
    [LoRA_USBStick.kicad_pcb]
2020-02-25 Update relay stick
2020-08-03 fix enable LDO
    [LoRA_USBStick.sch]
2020-08-03 Fix layout on enable LDO
    [LoRA_USBStick.kicad_pcb]
2020-10-15 fix part number micro
    [LoRA_USBStick.sch]
2022-06-24 Replace the ATSAMD21E with RP2040
    [LoRA_USBStick.kicad_sch]
2022-06-24 Assigned footprints
    [LoRA_USBStick.kicad_sch]
2022-06-28 Change labels, assigned and check the footprints
    [LoRA_USBStick.kicad_pcb, LoRA_USBStick.kicad_sch]
2022-06-28 change labels for memory and RX_LED
    [LoRA_USBStick.kicad_sch]
2022-06-28 remove duplicate tags, I2C and UART
    [LoRA_USBStick.kicad_sch]
2022-06-28 change button for jumper force jumper
    [LoRA_USBStick.kicad_sch]
2022-06-29 Place footprints on the PCB
    [LoRA_USBStick.kicad_pcb, LoRA_USBStick.kicad_sch]
2022-06-30 add footprint memory flash
    [LoRA_USBStick.kicad_pcb, LoRA_USBStick.kicad_sch]
2022-07-01 New floor plan
    [LoRA_USBStick.kicad_pcb, LoRA_USBStick.kicad_sch]
2022-07-06 PCB route
    [LoRA_USBStick.kicad_pcb, LoRA_USBStick.kicad_sch]
2022-07-06 update floorplan and routing
    [LoRA_USBStick.kicad_pcb, LoRA_USBStick.kicad_sch]
2022-07-07 Change a fototprint and routing
    [LoRA_USBStick.kicad_pcb, LoRA_USBStick.kicad_sch]
2022-07-11 fix routing
    [LoRA_USBStick.kicad_pcb]
2022-08-09 Add labels
    [LoRA_USBStick.kicad_pcb]
2022-08-09 update labels
    [LoRA_USBStick.kicad_pcb]
2022-08-09 update label v3.0
    [LoRA_USBStick.kicad_pcb]
2022-08-16 update hex format in serial prints
2023-12-05 Updated images and links
    The CatWAN USB Stick image was added, the open-source certified image and link were improved, and the board purchase link was added.
2024-02-12 BOM updated
    [LoRA_USBStick.csv, LoRA_USBStick.kicad_sch]
2024-03-20 fix(Hw) Measurements in margen layer changed to user drawings
    [LoRA_USBStick.kicad_pcb]
2024-03-20 feat(Hw) Update version
    [LoRA_USBStick.kicad_pcb]
2024-04-24 feat(docs): add text and distributor button
2024-10-14 feat: stop simulation sensor
2025-03-11 fix: change name folder for bootloader SAMD21
    [update-bootloader-catwan-usb-stick-v3.4.0-70-g3a14b0b-dirty.ino]
2025-03-14 fix: restore functions that were previously removed
    [LoRaSniffer.ino]
2025-06-04 feat(pins): to define radio module pins
    To define radio module pins for supporting non-official cores (arduino-pico)
2025-06-04 fix: RFM_DIO0
    To change pin number for RFM_DIO0
    [LoRaReceiver.ino, LoRaReceiverCallback.ino, LoRaSender.ino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]
2026-10-12 docs: distributors button in the same style as the store and wiki buttons
2026-10-12 docs: distributors button with the same rounded typeface as the other buttons
2026-10-12 docs: a heading above the button row so the images read as links
